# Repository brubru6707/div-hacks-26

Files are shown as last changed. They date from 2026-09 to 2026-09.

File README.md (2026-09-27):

# DivHacks 2026 — Pi 5 Demo Node

Camera + PIR motion node on a Raspberry Pi 5, verified 2026-09-23. All four hardware tests pass.

## Hardware
- Raspberry Pi 5 Model B Rev 1.1, Raspberry Pi OS Lite, Debian 13 (Trixie), 64-bit.
- Arducam IMX219 NoIR camera on **CAM0**.
- HC-SR501 PIR sensor: OUT → GPIO4 (pin 7), VCC → 5V, GND → pin 6.
- One 850nm IR LED board, powered by its own power bank (not wired to the Pi).
- Powered by a 5V/3A USB-C supply (held fine, `throttled=0x0`). A 5V/5A supply is recommended for headroom.

## Test results
| Test | Result | Notes |
|---|---|---|
| 1. System health | PASS | Pi 5, 64-bit, no undervoltage |
| 2. Camera | PASS | needed `dtoverlay=imx219,cam0` + reboot |
| 3. PIR sensor | PASS | clean MOTION/clear on GPIO4 |
| 4. PIR triggers camera | PASS | 25 captures on motion, IR-lit (see `captures/`) |

## Key fixes
- `camera_auto_detect=1` alone did **not** bind the IMX219. Added `dtoverlay=imx219,cam0` to `/boot/firmware/config.txt` and rebooted.
- `picamera2` is not installed and the Pi has no internet (802.1X Wi-Fi blocks macOS Internet Sharing). Use `rpicam-still` instead, or `sudo apt install python3-picamera2` on a non-802.1X network.

## Reaching the Pi
Login: `pi` / `YOURPASSWORD` (sudo uses the same password).

It's on a direct Mac→Pi Ethernet cable (interface `en8`) with no DHCP, so link-local only. IPv4 self-assign is unreachable from macOS; use IPv6 link-local:
```
for i in 1 2 3; do ping6 -c1 ff02::1%en8 >/dev/null; done   # warm the link
ndp -an | grep 2c:cf:67 | grep %en8                          # find fe80::…%en8
ssh pi@<that-address>
```
The neighbor entry goes stale fast; warm before each connect, or hold an `ssh -M` ControlMaster with `ServerAliveInterval=5`. For the event, put the Pi on a switch/router with DHCP or set static IPs on both ends to end the flakiness.

## Files
- `captures/` — 25 PIR-triggered frames (`trig_*.jpg`) plus `cam_test.jpg` (plain Test 2 still). `trig_081020.jpg` clearly shows a hand lit by IR.
- `pir_test.py` — Test 3: prints MOTION/clear on GPIO4.
- `trigger_capture.py` — Test 4: captures a photo (via `rpicam-still`) on each motion event.
- `enclosure/` — parametric 3D-printable case. `enclosure.scad` (OpenSCAD) and `build_stl.py` (trimesh) generate `stl/`: `base_with_pisugar.stl`, `base_no_pisugar.stl`, and `lid.stl`. The node includes a PiSugar battery pack under the Pi; it's removable, hence the two base variants.
- `enclosure/v2/` — the current case (sensors on the front wall, IR light + camera + PIR in a row). `stl/` is the print set: `v2_base_usb.stl` (no PiSugar) or `v2_base_pisugar.stl`, plus lid, stand, shroud, diffuser and a front-wall test plate. The IR light pocket is cut to the vendor drawing by `fit_ir_light.py`; see `V2_NOTES.md`.
- `HANDOFF-pi5-camera-pir-node.md` — full handoff for whoever receives the hardware.
- `HANDOFF-barn-owl-dashboard.md` — the dashboard (barn-owl.tech), recording pipeline, and training-data status. Code in `dashboard/` and `pi/`.
- `HANDOFF-solana.md` — Solana track plan: on-chain, tamper-proof recording hashes with a live chain log on the dashboard; why the Ledger is optional.

Scripts live in `~/node-test/` on the Pi.

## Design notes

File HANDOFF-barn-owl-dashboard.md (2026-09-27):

# Barn Owl: dashboard, recording pipeline, and training data

Handoff for everything built on top of the Pi 5 camera node on 2026-09-26
(DivHacks). The hardware bring-up is in `HANDOFF-pi5-camera-pir-node.md`; this
file covers what came after: the web dashboard, how footage is recorded and
stored, and where the training data stands.

This repo is public. Secrets are **not** in this file; it says where each one
lives instead.

---

## 1. What exists, in one minute

| Thing | Where |
|---|---|
| Dashboard (primary) | **https://barn-owl.tech** (DigitalOcean droplet, shared with jenzombie) |
| Dashboard (backup) | https://barn-owl.vercel.app (same code, same database, no 15 fps features) |
| Dashboard login | ask Bruno. Stored as `DASH_USER` / `DASH_PASS` in the Vercel project env and `/etc/barn-owl/env` on the droplet |
| Pi program | `pi/agent.py`, runs as systemd service `barn-owl` on the Pi, starts at boot |
| Web app code | `dashboard/` (Node, no framework) |
| Databases | MongoDB Atlas free tier (512 MB), database `barn_owl` (media + live state), and **Tiger Data** (Tiger Cloud, TimescaleDB) for the time series, see 5 |
| All 15 fps videos as one zip | https://barn-owl.tech/api/videos-zip (must be logged in) |

What the dashboard does:

- **Live** tab: camera view at **1 fps** (default) or **15 fps** (barn-owl.tech only), zoom presets **1× / 1.5× / 2× / 2.5×**, rotate, PIR motion status + "last motion", IR light toggle, **● Record / ■ Stop**.
- **Recordings** tab: every recording as a MongoDB entry, with a 1 fps preview player, the raw document (`{ } Entry`), delete, and storage used out of 512 MB.
- **Videos (15 fps)** tab: each recording's full-rate video next to the matching 1 fps preview (synced by time), plus downloads: MP4, original MJPEG, frame-times `.txt`, and **Download all (.zip)**.
- **Totals bar** (every tab): recordings count/time, Pi frames/time/size, MongoDB preview frames/size.
- The page **dims** and the top-right says **Pi offline** when the Pi stops checking in (15 s grace).
- A browser stays logged in for a year (signed cookie).

---

## 2. How it fits together

```
                    campus Wi-Fi ("Columbia University", open)
   Raspberry Pi 5  ─────────────────────────────────────────────►  barn-owl.tech (droplet, Caddy → Node :8771)
   pi/agent.py                                                     │  /api/pi          state + 1 fps preview (every 1–3 s)
     • camera: one rpicam-vid, 640×480 @ 15 fps MJPEG              │  /api/stream-in   15 fps live push (only while watched)
     • PIR GPIO23, IR GPIO4                                        │  /api/video-in    finished 15 fps recordings
     • writes 15 fps recordings to ~/barn-owl/recordings           │  /srv/barn-owl/videos  (.mjpeg .txt .mp4)
     • uploads them when done                                      ▼
                     └── falls back to barn-owl.vercel.app ──► MongoDB Atlas (barn_owl) ◄── both sites read/write
```

The Pi is behind campus NAT, so nothing can connect *to* it. The Pi always
calls out: it POSTs its state every 3 s when idle, every 1 s while someone is
watching or recording. The site answers with "is anyone watching", "is a
recording on", pending IR command, and zoom.

Both sites share one MongoDB, so whichever the Pi reaches, both dashboards
show the same thing. If barn-owl.tech is down the Pi switches to Vercel within
a second and retries the droplet every 60 s.

---

## 3. Training data (the important part)

### 3.1 How to record a clip

1. Open https://barn-owl.tech → **Live**.
2. Pick the **zoom** first (it is locked during a recording, and stored on the entry).
3. Turn the **IR light** on if shooting dark (it auto-offs after 2 min to avoid overheating; clips longer than that need it re-toggled).
4. **● Record**. Move the prop. **■ Stop**.
5. A few seconds later the clip appears on **Videos (15 fps)**. Recording keeps going even if you close the page or Wi-Fi drops (it uploads when the Pi is back online). Hard cap: 30 min per recording.

### 3.2 What a recording produces

| Copy | Resolution / rate | Where | Use |
|---|---|---|---|
| Original | 640×480, **15 fps**, MJPEG (quality 80), full sensor field of view | Pi: `~/barn-owl/recordings/<local-time>_<id>.mjpeg` and droplet: `/srv/barn-owl/videos/<id>.mjpeg` | **training** |
| Frame times | one line per frame: ms since start | `<same name>.txt` | exact timing; the camera can drop frames |
| MP4 | H.264, same frames, ~40× smaller | droplet only | watching |
| Preview | 480×360, ~1 fps, JPEG q60 (~14 KB) | MongoDB `frames` collection | browsing on the dashboard |

`<id>` is the MongoDB recording id. It matches across the Pi file, the droplet
file, the zip, and the dashboard entry.

### 3.3 Getting the data

- **Everything, from anywhere:** https://barn-owl.tech/api/videos-zip. Built fresh on each click. Files are named `<UTC start>Z_<id>.{mjpeg,txt,mp4}` and there is a `manifest.csv` (file, id, start, duration, frames, fps, zoom, sizes).
- **One clip:** Videos tab → download links on its card.
- **Straight off the Pi** (same network): `./pi/pull_recordings.sh` → `recordings/` in this repo (git-ignored).

Extracting frames:

```bash
# every frame of an original, as JPEGs
ffmpeg -f mjpeg -i clip.mjpeg -q:v 2 frames/clip_%05d.jpg
# every 5th frame (3 fps) to cut near-duplicates
ffmpeg -f mjpeg -i clip.mjpeg -vf "select=not(mod(n\,5))" -vsync vfr -q:v 2 frames/clip_%05d.jpg
```

The MJPEG is a plain concatenation of JPEGs, so `extract_frames.py`-style
readers that split on `FFD8…FFD9` also work.

### 3.4 Dataset status (as of 2026-09-26 ~20:15 UTC)

- **28 recordings at 15 fps → 17,288 frames, ~19 min**, 530 MB on the Pi. Zoom: 25 at 1×, 2 at 1.5×, 1 at 2×.
- **13 older recordings (18:00–18:40 UTC) are NOT usable alongside the rest**: they were captured before the fixes below, at 480×360, ~1 fps, and a **cropped (zoomed-in) field of view**. They exist only as 1 fps previews in MongoDB, not as videos.

### 3.5 Camera facts that matter for training

- **Field of view.** Asking rpicam for 640×480 used to select the sensor's 640×480 mode, which reads only the central 1280×960 of the 3280×2464 sensor (≈39 % of the view). The agent now forces `--mode 1640:1232:10:P` (full sensor, 2×2 binned) and scales to 640×480. Everything recorded from 18:52 UTC on uses the full view; earlier footage is the cropped one.
- **Zoom presets** are centred `--roi` crops of that full-view image. Up to 2.5× the crop is still ≥ 640×480 sensor pixels, so it is real detail, not an upscale. Keep the subject near the centre when zoomed.
- **Exposure is automatic** right now. To lock it (e.g. your teammate's IR-night settings) set `OWL_CAM_EXTRA="--gain 8 --shutter 30000 --awb greyworld"` in `/etc/barn-owl.env` on the Pi and `sudo systemctl restart barn-owl`. That applies to the live view, recordings and the demo alike. Those IR settings were tuned for a dark room and may blow out the steel table under room lights.
- NoIR camera: colours have a magenta cast; black synthetic fabric (and the prop) can glow under 850 nm IR. Training in grayscale sidesteps both.

### 3.6 Review of the footage so far, and what to shoot next

What's good: strong contrast between the black prop and the brushed steel,
many positions/headings, partial (edge) views, empty-table frames, a
string-only/cable negative, no clipped highlights (mean brightness ≈110/255).

What to change:

1. **Variety of background.** The same spot of the same table with the same bright lamp reflection and the same black box is in nearly every frame. The model can memorise those. Move the prop around the table, add the floor if the demo might be there, add distractors (hoodie, bag, hands, shoes, cables near the prop).
2. **Distances.** Record a set at each zoom preset (1×, 1.5×, 2×, 2.5×) or at three real camera heights. Match whatever the demo mount will be.
3. **Motion vs. near-duplicates.** Static-prop clips add frames but little information. Keep the prop moving; subsample static clips (every 5th frame).
4. **Negatives.** Empty table, string only, hands only, dark objects that aren't the rat.
5. **IR / dark footage.** None yet. Lights off, IR on (from the dashboard).
6. **Demo location.** If you find out where you present, record a couple of minutes there right before.
7. **Split by recording, not by frame.** Hold out whole recordings (whole sessions ideally) for validation; adjacent frames are near-identical and leak across a random split.

### 3.7 The string

The prop is pulled on a string for now. Options, best first:

1. **Label only the rat** (never the string) and include **string-only** clips as negatives. The model learns the string isn't the rat, no editing needed. If the demo also pulls the prop on a string, this is the right choice, because the model will see the string live.
2. **Clear fishing line** for future clips: close to invisible, especially under IR.
3. **Remove it afterwards** (thin dark line → mask → OpenCV `inpaint`). If you do, do it to *every* frame including negatives, or the inpainting smudge itself becomes a "rat is here" cue.

---

## 4. The Pi

| | |
|---|---|
| Model | Raspberry Pi 5, Raspberry Pi OS Lite (Debian 13), hostname `raspberrypi` |
| Login | user `pi` (password in `CREDENTIALS.txt` locally; it's also in `README.md`, so **change it**) |
| Wi-Fi | "Columbia University" (open network; the Pi's chip can't do the OWE variant, so the NetworkManager profile is plain open). Power saving **off** (it caused multi-second stalls). Address seen: `10.206.18.8` |
| Ethernet | `eth0` is link-local only (it used to wait for DHCP forever and reset the link) |
| SSH from a Mac on campus Wi-Fi | `ssh pi@10.206.18.8` (key auth set up from Bruno's Mac) |
| SSH over the cable | IPv6 link-local, see the older handoff. macOS keeps turning IPv6 off on the USB adapter: `networksetup -setv6LinkLocal "USB 10/100/1000 LAN"` |
| Service | `barn-owl` (`/etc/systemd/system/barn-owl.service`), code in `~/barn-owl/agent.py`, logs: `journalctl -u barn-owl -f` |
| Config | `/etc/barn-owl.env` (root-only): `OWL_URLS`, `OWL_TOKEN`, `OWL_PIR_PIN=23`, `OWL_IR_PIN=4`, `OWL_IR_MAX_ON=120`, optional `OWL_CAM_EXTRA`, `OWL_CAM_FPS`, `OWL_REC_DIR`, `OWL_STREAM_URL` |
| Extra package | `python3-pil` (shrinks previews) |

**Wiring (HC-SR501 PIR):** VCC → pin 2 or 4 (5 V), OUT (middle pin) → **pin 16 (GPIO23)**, GND → pin 6.
It was stuck on "Motion" for hours because **VCC and GND were swapped**; fixed.
Knobs: time-delay fully counter-clockwise (~3 s hold), jumper on **L**; the
sensitivity knob sets range. **IR light:** switched by **GPIO4**, auto-off after
2 min (`OWL_IR_MAX_ON`) because it overheats.

Deploying agent changes: copy `pi/agent.py` to `~/barn-owl/agent.py` and
`sudo systemctl restart barn-owl`.

---

## 5. Hosting

### Droplet (barn-owl.tech)

- The existing **jenzombie** droplet `104.248.231.139` (nyc1). barn-owl runs next to jenzombie; jenzombie is untouched except one line appended to `/etc/caddy/Caddyfile`: `import /etc/caddy/sites/*.caddy` (backup: `Caddyfile.pre-barn-owl`). **If jenzombie's own `provision.sh` is re-run it overwrites the Caddyfile and barn-owl disappears**; re-run barn-owl's provision (below) or add that import line to the jenzombie repo's `server/Caddyfile`.
- Node service `barn-owl-web` on `127.0.0.1:8771` (hardened unit; writes only `/srv/barn-owl/videos`). Secrets in `/etc/barn-owl/env`.
- Caddy site file `/etc/caddy/sites/barn-owl.caddy` (from `dashboard/deploy/barn-owl.caddy`): TLS, `flush_interval -1` for the live stream, and a log filter that deletes `Authorization`, `Cookie` and `Set-Cookie` (verified: 0 hits for the token in the log).
- DNS: DigitalOcean zone `barn-owl.tech`, A records for apex + `www` → droplet, TTL 300. Registrar (get.tech/Namify) nameservers → `ns1/ns2/ns3.digitalocean.com`. Let's Encrypt certs for both names.
- Deploy from a Mac:
  ```bash
  cd dashboard
  BO_HOST=root@104.248.231.139 BO_SITES="barn-owl.tech, www.barn-owl.tech, barn-owl.104-248-231-139.sslip.io" ./deploy/push.sh
  # add --secrets to (re)write /etc/barn-owl/env from dashboard/.env.local
  ```
  `push.sh` rsyncs the app and runs `deploy/provision.sh` on the droplet (idempotent: Node 22, ffmpeg, zip, user, service, Caddy, checks).

### Vercel (backup)

- Project `barn-owl` in the `brubru6707s-projects` team. `cd dashboard && vercel deploy --prod`.
- Env: `DASH_USER`, `DASH_PASS`, `SESSION_SECRET`, `PI_TOKEN`, `MONGODB_URI` (the last from the MongoDB Atlas integration). `vercel env pull` writes them to `dashboard/.env.local` (git-ignored).
- Vercel functions can't hold connections open, so **15 fps live, Videos and the zip only work on barn-owl.tech**. Vercel shows 1 fps and links to the droplet for videos.

### MongoDB (`barn_owl`)

| Collection | Contents |
|---|---|
| `node` | one document `{_id:'node'}`: Pi state, latest preview frame, viewer timestamps, pending IR command, zoom, recording in progress |
| `recordings` | one entry per Record→Stop: start/end/duration, zoom, preview count/bytes, `pi` (file/frames/fps/bytes), `video` (status/frames/fps/sizes) |
| `frames` | 1 fps preview JPEGs `{rec, ts, jpeg}` (kept out of `recordings` because a document is capped at 16 MB) |

Live viewing never adds storage (the `node` document is overwritten). Only
recording previews accumulate, ~14 KB/s of recording.

---

### Tiger Data (time series, for the "Best Use of Tiger Data" track)

MongoDB keeps media and live state; **Tiger Data (TimescaleDB on Postgres,
Tiger Cloud service `db-41897`, us-east-1)** keeps everything that happens over
time. Code: `dashboard/lib/tiger.js` (schema is created on first use, idempotent).

| Object | Kind | What |
|---|---|---|
| `readings` | hypertable (1 h chunks), **compressed** after 1 h (columnstore policy) | one row per Pi check-in: pir, ir, zoom, camera_on, recording, cpu_temp_c, wifi_dbm |
| `motion_events` | hypertable | one row per stretch of PIR motion (written on the rising edge, closed on the falling edge) |
| `detections` | hypertable | rat detections: ts, recording, frame, label, confidence, box x/y/w/h (0–1), model |
| `recordings` | table | same ids as MongoDB (41 backfilled with `deploy/backfill-tiger.js`); joins detections/motion to clips |
| `activity_1m`, `activity_1h` | continuous aggregates (hierarchical) | motion share, IR share, CPU temp per minute / hour |
| `detections_1m` | continuous aggregate | detections and best confidence per minute |

The dashboard's **Activity** tab reads only the continuous aggregates and
shows rows stored, compression saved, motion events, detections and query time.

**Posting detections (for the model):**
```bash
curl -X POST https://barn-owl.tech/api/detections \
  -H "Authorization: Bearer $PI_TOKEN" -H "Content-Type: application/json" \
  -d '[{"recording":"<recording id>","frame":123,"confidence":0.91,"box":[0.40,0.35,0.12,0.08],"model":"yolo-v1"}]'
```
Send one object or an array (a whole clip at once is one insert). `ts`
defaults to now; for offline runs over a downloaded clip, pass the frame's
real time (recording start + the `.txt` offset). `GET /api/detections` (logged
in) returns the latest 100.

Useful SQL (connect with the string in `~/.barn-owl/tiger_url` on Bruno's Mac):
```sql
-- rats per clip, best confidence
select r.id, r.started_at, count(d.*) as rats, max(d.confidence) as best
from recordings r left join detections d on d.recording = r.id
group by r.id order by r.started_at desc;
-- clips where the model saw a rat but the PIR never fired
select distinct d.recording from detections d
where not exists (select 1 from readings x where x.recording = d.recording and x.pir);
-- compression
select * from chunk_compression_stats('readings');
```

TLS: Tiger Cloud signs with its own root (`ca.timescale.com`), pinned in
`dashboard/lib/timescale-ca.pem` (expires 2027-10-20), so the connection is
verified rather than `rejectUnauthorized: false`. `TIGER_DATABASE_URL` is set
in Vercel and `/etc/barn-owl/env` on the droplet; without it the site runs as
before and the Activity tab says Tiger isn't configured.

## 6. Gotchas we hit (so you don't)

- The HC-SR501 read HIGH forever: VCC/GND swapped. Pulling OUT off pin 16 made the pin read LOW, which proved the Pi side was fine.
- The dashboard flickered offline: Wi-Fi power saving on the Pi's Broadcom chip. Disabled in the NetworkManager profile.
- "Zoomed in" camera: the 640×480 sensor mode is a centre crop (see 3.5).
- This Mac's resolver answers `127.0.0.1` for `barn-owl.tech` (something local intercepts DNS). Chrome works; `curl` on the Mac may not. Verify from the droplet instead.
- Chrome won't load `<video>` in a background tab, so automated checks of the Videos tab can look stuck when they aren't.
- Deleting a recording on the dashboard removes MongoDB + droplet copies but **not** the Pi original (on purpose).
- Zoom is locked during a recording; changing zoom restarts the camera (~2 s).

---

## 7. Costs and cleanup

- **Money:** only the droplet (~$6/mo), which was already running for jenzombie. The DO account had $3.65 signup credit on 2026-09-26 (≈17 days); after that the card on file is billed. Powering a droplet off does not stop billing; destroying it does. Vercel Hobby and MongoDB Atlas free tier: $0. `barn-owl.tech` is paid until 2027-09-26, **auto-renew off** ($29.99/yr).
- **To move off the droplet later for $0:** add `barn-owl.tech` to the Vercel project, point DNS at Vercel, destroy the droplet (only once jenzombie is done too). You'd lose 15 fps live/Videos/zip unless reworked.
- **Tiger Cloud:** 30-day trial ($1,000 credit, no card). Delete service `db-41897` when done or it will need a plan.
- **Secrets to rotate/revoke when done:** the Tiger Cloud `tsdbadmin` password (it was pasted into a chat); `PI_TOKEN` (Vercel env, droplet `/etc/barn-owl/env`, Pi `/etc/barn-owl.env`, Bruno's Mac `~/.barn-owl/pi_token`); `SESSION_SECRET`; the MongoDB Atlas user; the Pi password (public in `README.md`); the dashboard password (it's short, so change it before anything public).
- **Not committed yet (as of writing):** `dashboard/`, `pi/`, this file. `dashboard/.env.local` and `recordings/` are git-ignored.

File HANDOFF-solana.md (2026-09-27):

# Handoff — Solana track: tamper-proof recordings

Planning notes for adding Solana to Barn Owl for the DivHacks 2026 Solana track: what we decided and why. The first version is now built into the dashboard (next section). The Pi-side chunk hashing described further down is not built yet.

## What's built (2026-09-26): the dashboard's Solana tab
The **dashboard server** anchors evidence on Solana **devnet** with its own key. The Pi doesn't sign anything yet.

- **What gets anchored**
  - Every detection POSTed to `/api/detections`: the SHA-256 of a canonical JSON form of the row. Memo: `owl1 det <hash>`.
  - Every 15 fps recording the Pi uploads: the SHA-256 of the `.mjpeg` file. Memo: `owl1 rec <id> <hash>`. This runs on the droplet only (Vercel doesn't store the videos).
  - Up to 5 memos go in one transaction, signed by `SOLANA_ANCHOR_KEY`.
- **Code**
  - `dashboard/lib/solana.js`: hashing, a send queue (MongoDB collection `anchors`), confirmations, resends.
  - `dashboard/api/solana.js`: the tab's API.
  - Hooks: `api/detections.js` and `lib/videos.js`.
  - Anchoring never blocks or fails an upload. Anything unsent is retried whenever the tab polls, which also makes it work on Vercel.
- **The tab**
  - Anchor count, the key's address and balance (with an **Airdrop** button on devnet).
  - A **live chain log**: the browser subscribes to Solana over WebSocket (`logsSubscribe`), so rows flip to "✓ confirmed live" the moment the chain confirms them, without going through our server.
  - **Verify** on each row: the server recomputes the hash from the data as stored now (the Tiger Data row, or the file on disk), and the browser reads the memo from the chain itself and compares the two. For a detection, it lists which fields changed.
  - **Drop a file**: hash a downloaded original MJPEG in the browser and check it against the chain.
  - A "what this proves / doesn't" note.
- **Setup**
  - `SOLANA_ANCHOR_KEY` is a JSON byte array, like `solana-keygen` writes. It's in `dashboard/.env.local`; a backup is at `~/.config/solana/barn-owl-anchor-devnet.json`.
  - Optional: `SOLANA_CLUSTER` (default `devnet`), `SOLANA_RPC`, `SOLANA_PUBLIC_RPC`.
  - `deploy/push.sh --secrets` now ships `SOLANA_*` vars to the droplet. On Vercel, add the variable with `vercel env add SOLANA_ANCHOR_KEY`.
  - If the key isn't set, nothing is anchored and the tab says so.
- **Tamper demo:** change one field of a detection in Tiger Data (e.g. `update detections set confidence = 0.99 where …`), or flip a byte in a `.mjpeg` on the droplet, then press **Verify**.
- **Not built yet:** the Pi signing with its own key, and live 10-second chunk hashing while recording (both described below).

## TL;DR
- **Build:** the camera hashes its footage every ~10 seconds while recording and writes each hash to Solana (devnet). The dashboard shows those hashes landing on-chain **live**, next to the video.
- **Skip the Ledger** (the Nano S Plus won at a previous hackathon) unless there's time left at the end. It's a nice extra, not the core.
- **Don't use Solana to pay for the device.** That's just a checkout page and has nothing to do with what Barn Owl does.

## The pitch
Barn Owl is an unattended IR night camera. With this feature it becomes a camera that **proves its own footage hasn't been edited**:

> "Every 10 seconds of footage is fingerprinted and posted to Solana, signed by the camera itself. Watch the fingerprints confirm on-chain as the owl moves. Later, anyone can drop in a clip and check it wasn't cut or altered."

Why this fits Solana: it needs a chain that's fast (confirmations in about a second, so the ticker feels live) and cheap (hundreds of transactions per hour). This matters for wildlife research, citizen science and evidence of poaching or trespass.

## Ideas we considered
| Idea | Verdict |
|---|---|
| Pay for the device with Solana | ❌ Weak. It's generic e-commerce and doesn't use anything about the camera. |
| Hash each finished recording on-chain | ✅ Good, but you wait up to 30 min (the `REC_MAX`) for one hash. |
| **Hash ~10s chunks, linked together, shown live** | ✅✅ **Chosen.** Visual, real-time, and a stronger claim. |
| Solana Pay QR code: tip the node, or pay to turn on the IR light or start recording | 🟡 Stretch goal. Fits the existing dashboard → Pi commands. |
| Ledger as the owner/treasury key | 🟡 Optional, last. See below. |

## How it works

### Hash chaining
While a recording is on, the Pi groups frames into ~10s chunks. For each chunk:

```
chunk_hash_n = SHA256( prev_hash || SHA256(all JPEG bytes in chunk n) || frame times )
```

The first chunk uses the recording ID as `prev_hash`. Because each hash includes the one before it, the hashes form a chain: you can't delete, reorder or edit a chunk without breaking every hash after it.

Each chunk hash goes on-chain as a **Memo program** transaction (no custom smart contract needed), e.g.:

```
owl1|<recording id>|<chunk #>|<chunk hash hex>
```

### Who signs
- **The camera signs with its own key**: a Solana keypair generated on the Pi and stored on the SD card (e.g. `~/barn-owl/device-key.json`, mode 600). Keep only a little SOL in it for fees; on devnet, use the airdrop.
- The camera's public address is shown on the dashboard. Filtering the explorer by that address shows everything the camera has ever posted.

### Where the code goes
- `pi/agent.py`: `Recorder.write()` already sees every frame. Keep a running SHA-256 per chunk there, and every ~10s close the chunk, chain it, and queue the hash. `Recorder._close()` closes the final partial chunk.
- **Sending transactions:** we don't know yet whether the Pi will have normal internet at the venue (campus 802.1X Wi-Fi blocked it before; today it reaches the dashboard via `/api/pi`).
  - Plan: **the Pi always signs.** If it can reach a Solana RPC, it sends the transaction itself. If not, it hands the signed transaction to the dashboard in its normal `/api/pi` sync, and the server sends it. The camera's signature is what matters, so the proof holds either way.
  - Chunk hashes must be queued on disk so recordings made offline still get posted later (same idea as the existing `Uploader` and its `.uploaded` markers).
- **Dashboard:**
  - **Live chain-log panel** next to the video. The browser subscribes to Solana over WebSocket (`onLogs` on the camera's address), so rows appear the moment the chain confirms them. The page watches the chain itself rather than trusting our server.
    ```
    ● LIVE  Chain log — barn-owl-01
    21:04:12  rec 0419 #3  a3f9…c21e  ✓ confirmed  [explorer]
    21:03:58  rec 0419 #2  77b0…9e04  ✓ confirmed  [explorer]
    21:03:44  rec 0419 #1  e12c…0af3  ✓ confirmed  [explorer]
    ```
  - **"Verified on Solana ✓" badge** on each saved recording in the recordings list.
  - **Verify page:** drop in a downloaded `.mjpeg` + `.txt`, re-hash the chunks in the browser, and compare them with the on-chain memos. It shows ✓ for each chunk, or exactly which chunk was tampered with.
    - Chunk boundaries must be reproducible from the file alone. Split on the frame times in the `.txt` (e.g. every 10,000 ms), not on wall-clock time at record time.

### Build order
1. Generate the Pi device key and fund it on devnet. Post one test memo from the Pi, or through the dashboard relay.
2. Chunk hashing + chaining in `Recorder`, with an on-disk queue and posting.
3. Live chain-log panel on the dashboard.
4. Verified badge + verify page.
5. *(Stretch)* Solana Pay QR code for tips or "pay to turn on the IR light."
6. *(Stretch)* Ledger as owner (below).

## The Ledger — why we're skipping it
The question was: "would the Ledger make a hash for every recording, and would I see it on the Ledger?" **No.**

- A Ledger needs a **human to press a button for every signature**. The camera runs unattended at 3am, so it can't sign the recording hashes.
- Leaving the Ledger plugged into the Pi would be worse: whoever stole the Pi would get the main wallet.
- The Ledger's screen only shows a transaction while you're approving it. It can't display a live feed, so the "see hashes in real time" part belongs on the dashboard.

In a full design, the Ledger would be the **owner/treasury key**, kept away from the camera, used rarely: receiving tips (receiving doesn't even need it plugged in), moving funds out, approving a new camera, revoking a stolen one. The Pi's throwaway key signs the routine hashes. If the Pi is stolen, the thief gets a few cents of fees and the owner revokes that camera.

**Decision:** the hashing is the project, and the Ledger adds setup risk (Ledger Live, the Solana app, wallet connection, possibly blind signing) for little demo value. No judge will mark us down for skipping it. **If there's time at the end:** make the Ledger's address the recipient of Solana Pay tips and name it as the camera's "owner" in the pitch ("the owner key lives on hardware, away from the field device"). That's about 10 minutes of work.

If we do use it: install the Solana app on the Ledger through Ledger Live and connect via Phantom or Solflare on devnet. Plain transfers and memos don't need blind signing; a custom program probably would.

## Demo script
1. Show the dashboard: live video, an empty chain log, the camera's Solana address.
2. Press **Record**, then wave a hand in front of the camera under the IR light.
3. Within a couple of seconds, chunk hashes start scrolling into the chain log, each marked ✓ confirmed. Click one to open the Solana explorer and show the memo signed by the camera.
4. Stop the recording. It shows up with **Verified on Solana ✓**.
5. Download the clip, remove a few frames (or flip bytes), and drop it on the verify page. The chunks before the edit show ✓; the edited chunk and everything after it show ✗.
6. *(If built)* Someone scans the Solana Pay QR code and tips 0.01 SOL to the owner address.

## Open questions
- Will the Pi have normal internet at the venue? (Decides whether it sends transactions directly or through the dashboard; the plan supports both.)
- Chunk length: 10s is the working choice. Shorter makes the ticker livelier; longer means fewer transactions.
- Devnet only for the demo? (Assumed yes.)

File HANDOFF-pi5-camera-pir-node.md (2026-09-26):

# Handoff — Pi 5 Camera + PIR Motion Node (DivHacks 2026)

You're getting a Raspberry Pi 5 set up as a motion-triggered camera node. Everything below is what it is, how to get into it, and the few gotchas that will otherwise cost you an hour.

## What it does (already built and tested)
A PIR motion sensor triggers the camera to take a photo. The camera is a NoIR (no infrared filter), so with an IR light it sees in the dark. All four hardware checks passed on 2026-09-23:

| Check | Status |
|---|---|
| Pi 5 boots, 64-bit OS, no undervoltage | working |
| IMX219 camera detected and captures | working |
| PIR sensor reports motion on GPIO4 | working |
| Motion triggers a photo (25 IR-lit frames captured) | working |

Sample photos are in `captures/` in this folder. `trig_081020.jpg` shows a hand lit by infrared.

## What's in the box
- Raspberry Pi 5 with the microSD card already imaged (Raspberry Pi OS Lite, 64-bit).
- Arducam IMX219 NoIR camera, ribbon into the **CAM0** connector.
- HC-SR501 PIR sensor, wired to the Pi: OUT → GPIO4 (physical pin 7), VCC → 5V (pin 2 or 4), GND → pin 6.
- One 850nm IR LED board with its own power bank (this is a light, it does **not** connect to the Pi).
- **PiSugar battery pack** mounted under the Pi so the node can run untethered. It is removable — pop it off and power the Pi straight from USB-C. The case has two variants for exactly this (see the enclosure section).
- Camera ribbon is ~12 cm, so the camera can sit up to that far from the Pi.

## Login
```
username: pi
password: YOURPASSWORD
```
`sudo` uses the same password. Please change it once you're in (`passwd`).

## Powering it
Use a **5V/3A USB-C supply minimum**; a 5V/5A (27 W) official Pi 5 supply is better and gives headroom for the camera. A phone charger rated only 2A will not boot a Pi 5 reliably. It ran clean on 3A during testing.

## Getting into the Pi — pick the easiest for your setup

**Option A — monitor + keyboard (simplest).** Plug a monitor into the **micro-HDMI port nearest the USB-C jack**, add a USB keyboard, power on, and log in with the credentials above. No network needed.

**Option B — network with a router/switch (best for headless).** Plug the Pi's Ethernet into any router or switch that hands out addresses (DHCP). SSH is already enabled. From another computer on that network:
```
ssh pi@raspberrypi.local
```
If the name doesn't resolve, find the Pi's IP in your router's device list and use `ssh pi@<ip>`.

**Option C — direct cable straight to a laptop (what we did, and it's fiddly).** With no router there's no DHCP, so both ends fall back to link-local addressing, which is flaky and OS-specific. On macOS it took IPv6 link-local gymnastics (see `README.md` in this folder for the exact commands). **Avoid this if you can.** Use Option A or B instead.

**Wi-Fi is not configured.** If you want wireless, connect by Option A or B first, then run `sudo raspi-config` (or `nmcli`) to add your network.

## Running the demo
The test scripts are on the Pi in `~/node-test/` (copies are also in this folder):
```
python3 ~/node-test/pir_test.py          # prints MOTION / clear as you wave at the PIR
python3 ~/node-test/trigger_capture.py   # takes a photo on each motion event
```
Stop either with Ctrl+C. For the camera-in-the-dark demo, power the IR board, aim it where the camera looks, dim the room, and wave your hand in view.

## 3D-printed enclosure
Case files are in `enclosure/`. Two base variants share one lid:

| File | Fits | Outer size (mm) |
|---|---|---|
| `stl/base_with_pisugar.stl` | Pi **with** the PiSugar under it | 93 × 64 × 43 |
| `stl/base_no_pisugar.stl` | Pi only (PiSugar removed) | 93 × 64 × 30 |
| `stl/lid.stl` | camera + PIR mount on top | 93 × 64 × 7 |

The only difference between the two bases is height: the PiSugar variant is ~13 mm taller to make room for the pack. The lid has a lens hole plus four Arducam (M2) mount holes near one end, and a 23.5 mm hole for the PIR dome near the other. Port openings are cut for the USB/Ethernet edge and the USB-C/HDMI edge.

Re-render after any change with either tool:
- `enclosure/enclosure.scad` in OpenSCAD (parametric; `include_pisugar` toggle), or
- `python3 enclosure/build_stl.py` (needs `pip install trimesh manifold3d numpy`).

Key parameters: `pisugar_h` (default 15 mm), wall thickness, clearances, and the port-window positions.

**Print + verify first.** The STLs are watertight and printable, but the dimensions were typed from measurements, not imported from a CAD model of the boards. Before a full print, dry-fit or print a test and check: the PiSugar height, the port windows against your board's actual orientation, and the camera/PIR hole placement. Nudge the parameters and re-render as needed.

## Gotchas that will bite you
- **microSD write-protect lock.** If you ever re-flash the card and writes are "permission denied," check the tiny slider switch on the card/adapter. It must be unlocked.
- **Camera needs an overlay.** `dtoverlay=imx219,cam0` is already in `/boot/firmware/config.txt` (backup at `config.txt.bak`). Auto-detect alone did not find the camera. If you swap SD images, you'll need to add that line again and reboot.
- **`picamera2` is not installed** and the Pi had no internet during setup, so the trigger script uses `rpicam-still`. If you want `picamera2`, put the Pi on internet once and run `sudo apt install python3-picamera2`.
- **The OS is Debian 13 (Trixie), 64-bit** — newer than the Bookworm most guides assume. Package names occasionally differ.
- **Verify the IR board is on** by pointing a phone camera at it; you'll see a purple-white glow. Your eyes can't see 850nm.

## Quick sanity check once you're in
```
cat /proc/device-tree/model        # Raspberry Pi 5 ...
vcgencmd get_throttled             # want throttled=0x0
rpicam-hello --list-cameras        # should list imx219
```

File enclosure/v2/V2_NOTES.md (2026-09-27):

# Enclosure v2

`node_v2.scad` is a new case built from the measured parts (Pi 5 + Active Cooler + PiSugar 3 Plus, Arducam IMX219, HC-SR501, IR light board). The v1 files are untouched.

Two power variants share the same lid, sensor wall and extras. Only the base differs:

| Variant | Base file | Power | Outer size (with lid) |
|---|---|---|---|
| **USB** | `stl/v2_base_usb.stl` | USB-C cable from a power bank, in through the side window | 107 × 96 × 45 mm |
| **PiSugar battery** | `stl/v2_base_pisugar.stl` | PiSugar 5000 mAh pack clipped magnetically under the PiSugar, inside the case. Charge through the same side window. | 107 × 96 × 57 mm |

In the battery variant the stack rests on the battery. A shallow tray locates the pack, and two walls stop the stack sliding toward the sensors or the cable bay. The pack is 67 × 55 × 12 mm as measured, with 3 mm of play on each side.

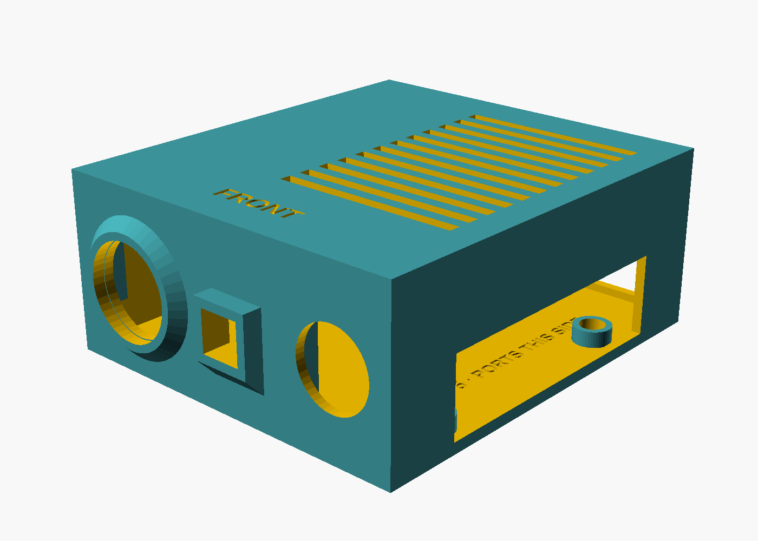
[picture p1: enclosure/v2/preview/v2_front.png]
front

inside

## What changed from v1

| | v1 | v2 |
|---|---|---|
| Sensors | camera + PIR on the lid, facing up | IR light, camera, PIR in one row on a flat **front** wall that presses against the diorama |
| USB-A / Ethernet | no opening (the port end faced a solid wall) | open **rear** wall |
| USB-C / HDMI / PiSugar ports | window on the wrong edge | window on the **port side**, tall enough for the PiSugar below the Pi |
| PIR vs USB stack | PIR above the USB ports (collision) | PIR beside the Pi, clear of it |
| Camera hole | 9 mm round (the square lens holder's diagonal doesn't fit) | 10.5 mm square, plus an outside hood so IR light doesn't flare into the lens |
| Cooling | one vent row | grille in the lid over the Active Cooler fan, plus side vents |
| Mounting | self-tap standoffs | sockets the PiSugar's studs drop into |
| Extras | none | cable bay beside the Pi, PIR shroud, clear PETG diffuser for the IR light |

## Print

| File | Material | Notes |
|---|---|---|
| `stl/v2_test_plate.stl` | black PLA | **Print this first** (front wall only). Check that the three sensors fit. |
| `stl/v2_base_usb.stl` or `stl/v2_base_pisugar.stl` | black PLA | Pick one. Prints as oriented (open top up). |
| `stl/v2_lid.stl` | black PLA | Already flipped: flat face down. |
| `stl/v2_stand.stl` | black PLA | Tilts the box 20° nose-down so the camera sees the floor. `tilt` in the file. |
| `stl/v2_pir_shroud.stl` | black PLA | Slides over the collar around the PIR dome to narrow its view. |
| `stl/v2_led_diffuser.stl` | clear PETG | Optional cap over the IR lens; softens the hot spot. |

Settings: 0.2 mm layers, 3 walls, 15% infill, no supports needed (the camera hood and PIR collar taper at 45° underneath). Glue stick for PETG. Don't print PLA and PETG fused together; they don't bond.

## Assembly
1. USB variant: drop the Pi + PiSugar stack onto the four sockets. Battery variant: clip the pack onto the PiSugar's magnet, plug its lead into the PiSugar's white socket, and set the whole stack in the tray. Either way, microSD end toward the front and USB-C/HDMI edge toward the port-side window ("PI 5 · PORTS THIS SIDE" is engraved on the floor).
2. Camera: lens holder through the square hole, board slides down between its rails, ribbon connector at the bottom. Hot-glue it.
3. IR light: lens through the round hole on the port side, board slides between the two rails. Hot-glue it. Its power lead runs along the sensor zone into the cable bay and out through the small rear notch.
4. PIR: dome through the big hole, board between its rails, hot-glue. Wires run to the GPIO header.
5. Lid on, with "FRONT" toward the sensor wall.
6. Set the box on the stand, front bottom edge against the lip. The holes in the diorama's back wall need to be a little taller than the sensors because the box is tilted.

## Assumptions to check on the test plate
- ~~IR light board is 21 mm wide (rails 21.8 mm apart).~~ Superseded by the measured fit below. PIR board is 32 mm wide.
- PiSugar ports are on the same long edge as the Pi's USB-C/HDMI (checked against the underside photo: the camera ribbon, which plugs into that edge, exits beside the PiSugar's ports).
- Battery variant: the stack sits loosely on the pouch. Add a strip of double-sided foam tape if it rattles. Don't let anything sharp press on the pouch, and don't use a pack that has puffed up.

Set `power = "usb"` or `"pisugar"` at the top of `node_v2.scad`. All sizes are variables there too. Change a number and run `./build_v2.sh` (needs OpenSCAD 2025+). **`node_v2.scad` is not in this repo**, only the STLs it produced (`original/`); see the next section for how the IR light fit is applied on top of them.

## IR light board fit (2026-09-25)

The vendor drawing for the 850 nm IR light replaces the guessed size. `fit_ir_light.py` patches the v2 STLs (the `.scad` isn't here, only its output) and writes the complete print set to `stl/`. The untouched v2 files stay in `original/`. Previews: `preview/v2_ir_fit_3d.png`, `preview/v2_ir_fit_sections.png`.

| | v2 guess | drawing |
|---|---|---|
| PCB | 21 wide | 19.82 × 27.94 × 1.0 mm, D-shaped (R10 top), solder pads 13.66 apart at the bottom ears |
| Lens | 19 dia (hole 19.8) | 19.0 dia, front face 14.05 in front of the PCB |
| Photoresistor | not modelled | 5.0 dia, tip 8.35 in front of the PCB, lower right of the lens seen from the front |
| Beam | | 100° |

What changed in the sensor wall (both bases, and the test plate):

- **Photoresistor hole**, 6.4 mm, merged with the lens hole into a keyhole. Without it the board could not get closer than 8.35 mm to the wall.
- **The PCB now seats 8.35 mm behind the outside face**, so the photoresistor tip is flush with the outside and the lens stands 5.7 mm proud, the same as the PIR collar and the camera hood. (v2 had the PCB against the wall and the lens 11.6 mm proud.) `PCB_FACE_X` in the script; set it to `2.4` for the old behaviour.
- **Rails** 20.4 mm apart (was 21.8) and 10.6 mm deep (was 5), from the floor to just above the lens axis. Three stops set the PCB depth: a post under the lens barrel (over the notch between the pads), a lip on the right, and a short lip on the left above the photoresistor. Hot-glue the board from behind, as before.
- `v2_led_diffuser.stl` is regenerated 7.2 mm tall for the shorter protrusion.
- `v2_lid.stl`, `v2_stand.stl`, `v2_pir_shroud.stl` are unchanged copies.

Assembly change for step 3: the IR board goes in from **behind**, straight along the lens axis. Lens into the round hole, photoresistor into the small hole, push until the PCB meets the stops. Solder the power wires on the back of the PCB first; they exit toward the cable bay.

Check on the test plate:

- Photoresistor position: 7.0 mm right / 9.3 mm below the lens axis was scaled off the drawing, so its hole is 1.4 mm oversize. If it doesn't line up, change `LDR_DX` / `LDR_DY` and rerun.
- The 8.35 was read as photoresistor tip to the PCB *front* face. If it is to the back face, the tip sits 1 mm inside the wall. Harmless.
- The centre post assumes the notch between the pads is at most ~4 mm deep (post top is 7 mm above the PCB's bottom edge). If the notch is deeper, the post misses and the two side lips set the depth alone.
- The PCB's bottom edge sits 1.06 mm above the floor.

```sh
pip install trimesh manifold3d numpy matplotlib
python3 enclosure/v2/fit_ir_light.py
```

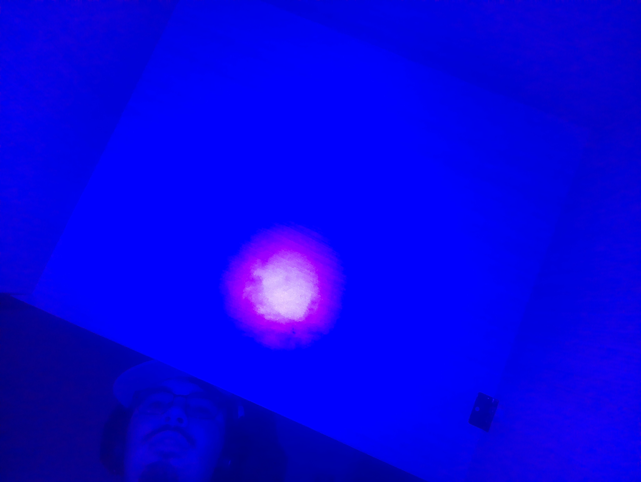
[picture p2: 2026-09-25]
captures/trig_081120.jpg

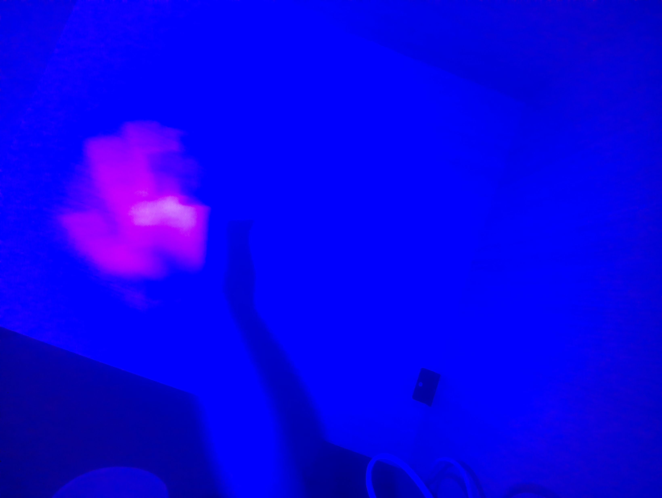
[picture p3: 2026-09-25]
captures/trig_081028.jpg

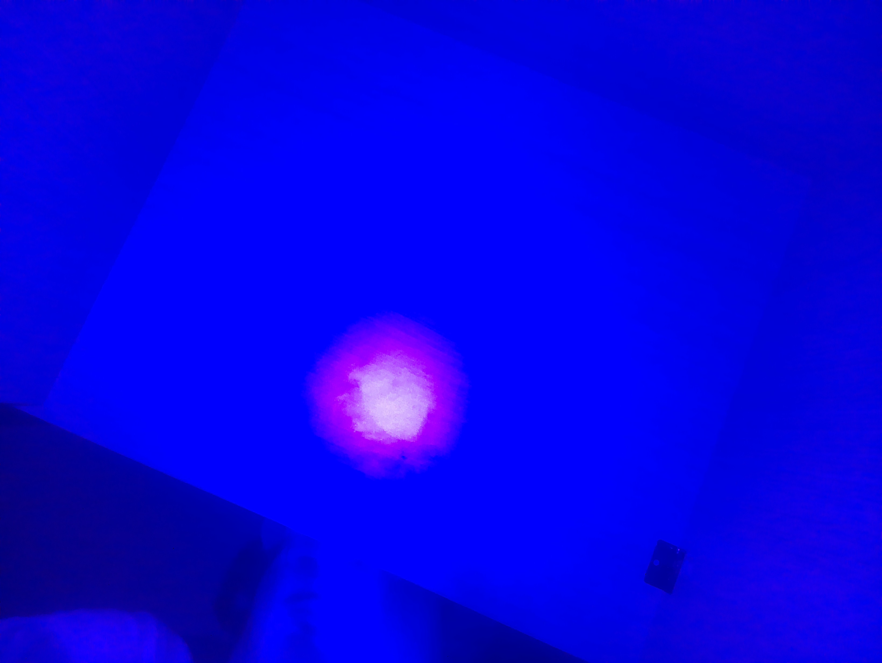
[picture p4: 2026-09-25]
captures/trig_081124.jpg

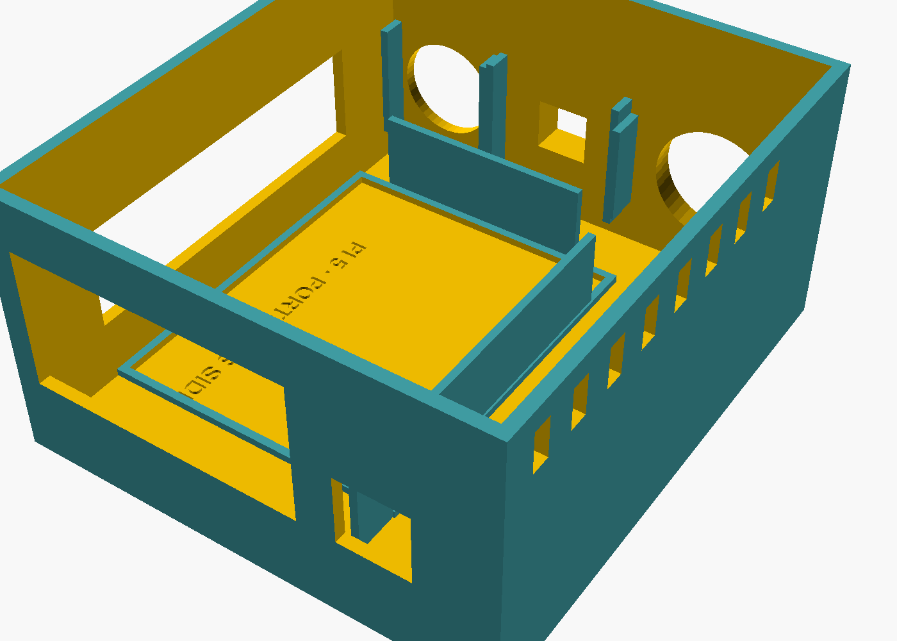
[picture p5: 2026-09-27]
enclosure/v2/preview/v2_inside_pisugar.png

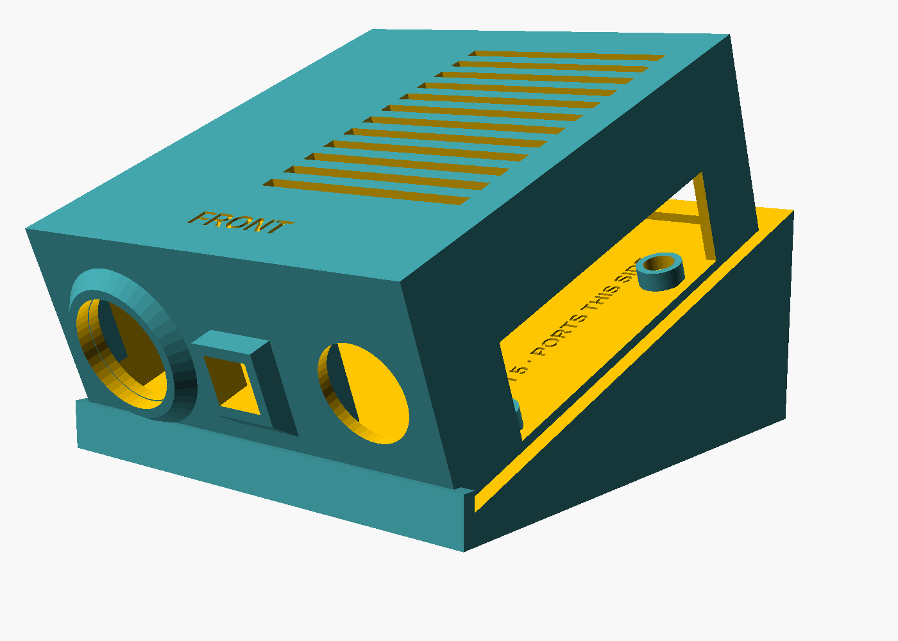
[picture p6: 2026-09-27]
enclosure/v2/preview/v2_on_stand.png

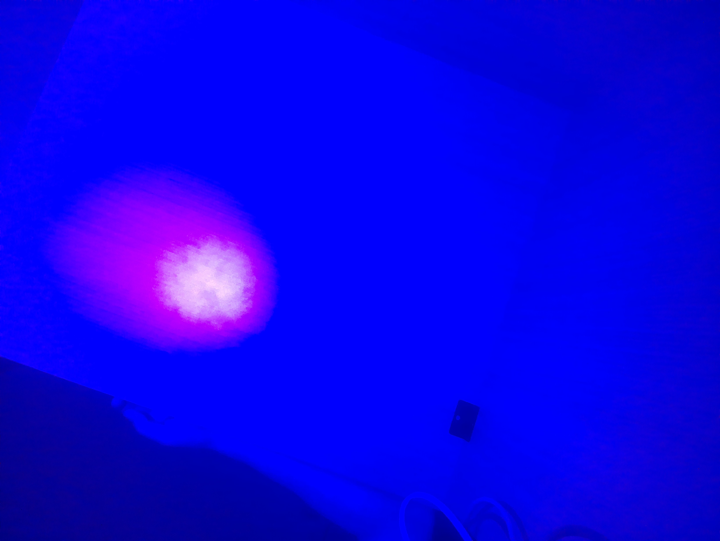
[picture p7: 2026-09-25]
captures/trig_080957.jpg

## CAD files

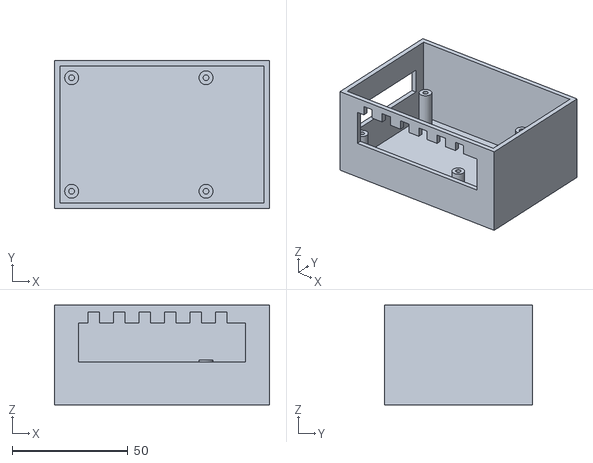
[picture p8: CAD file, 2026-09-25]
enclosure/stl/base_with_pisugar.stl
92.8 x 63.8 x 43.0

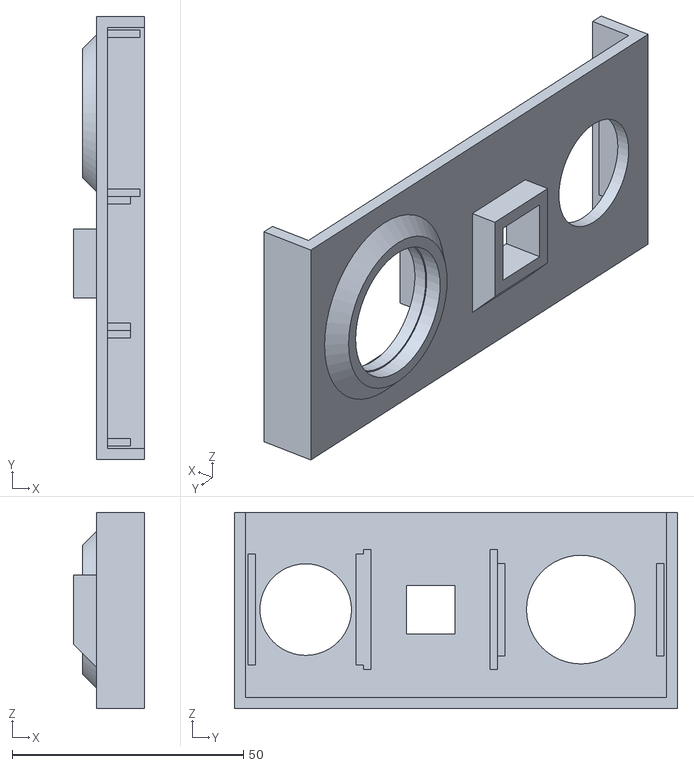
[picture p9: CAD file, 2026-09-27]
enclosure/v2/original/v2_test_plate.stl
15.4 x 95.8 x 42.4

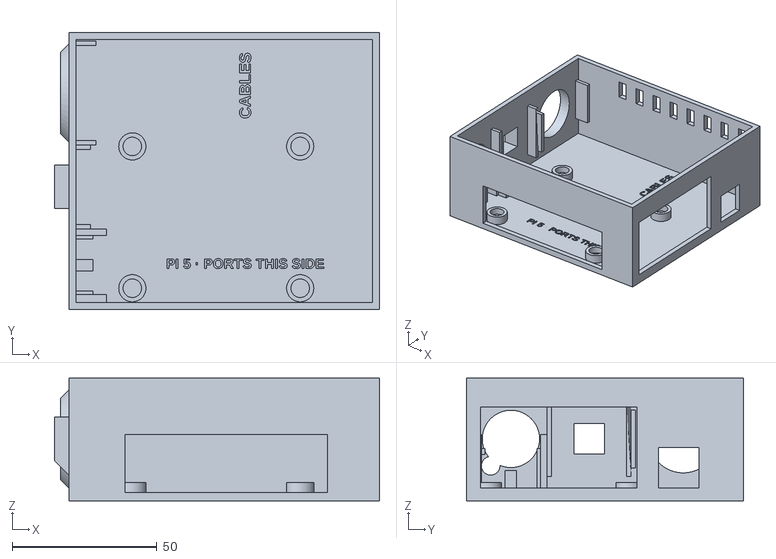
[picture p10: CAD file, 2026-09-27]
enclosure/v2/stl/v2_base_usb.stl
112.3 x 95.8 x 42.4

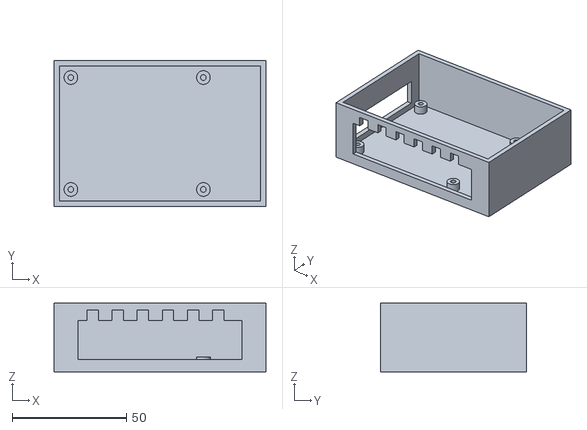
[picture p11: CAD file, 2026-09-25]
enclosure/stl/base_no_pisugar.stl
92.8 x 63.8 x 30.0

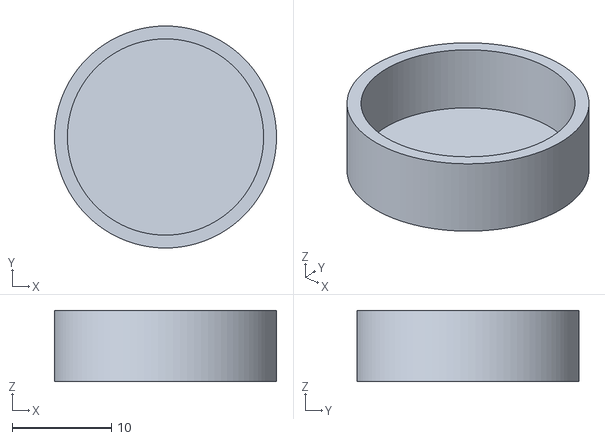
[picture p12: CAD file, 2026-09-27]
enclosure/v2/stl/v2_led_diffuser.stl
22.4 x 22.4 x 7.20

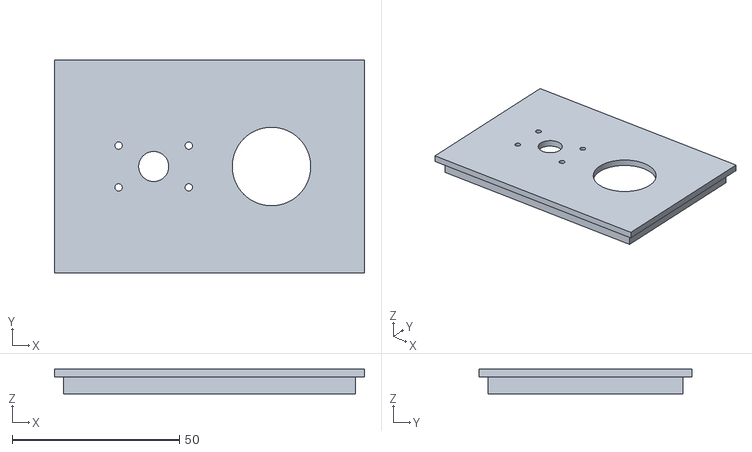
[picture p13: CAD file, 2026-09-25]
enclosure/stl/lid.stl
92.8 x 63.8 x 7.40

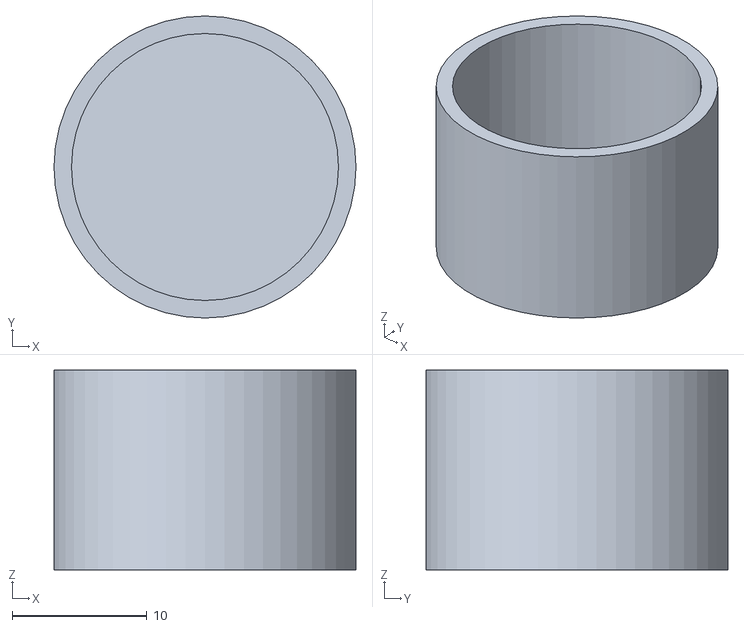
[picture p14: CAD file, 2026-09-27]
enclosure/v2/original/v2_led_diffuser.stl
22.4 x 22.4 x 14.8

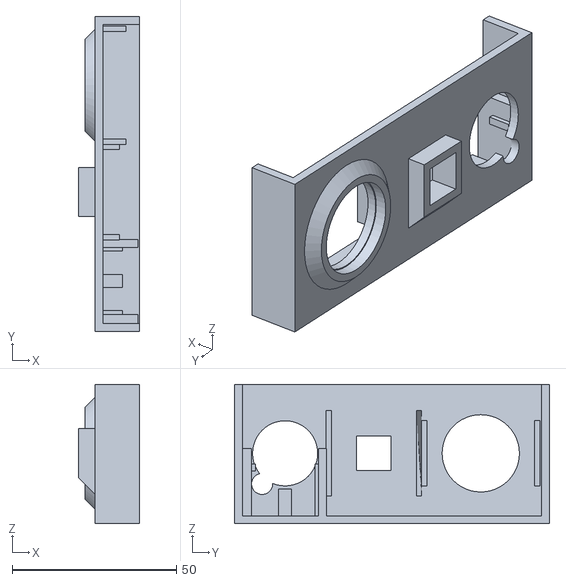
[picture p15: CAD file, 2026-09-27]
enclosure/v2/stl/v2_test_plate.stl
18.5 x 95.8 x 42.4

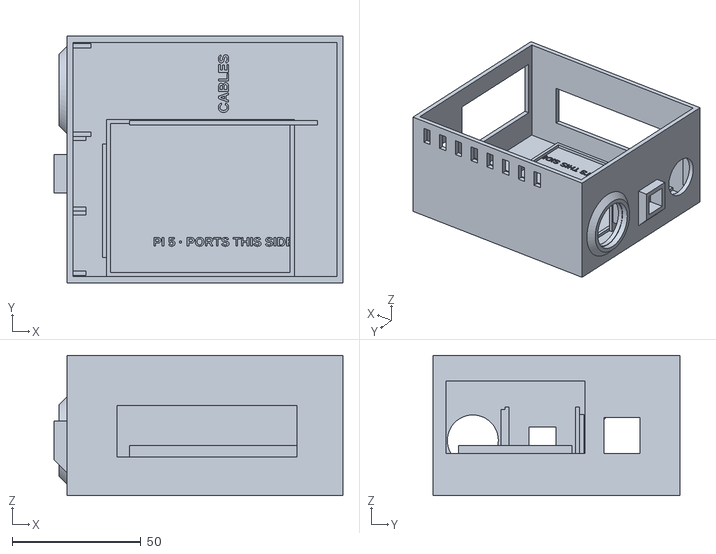
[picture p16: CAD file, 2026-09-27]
enclosure/v2/original/v2_base_pisugar.stl
112.3 x 95.8 x 54.4

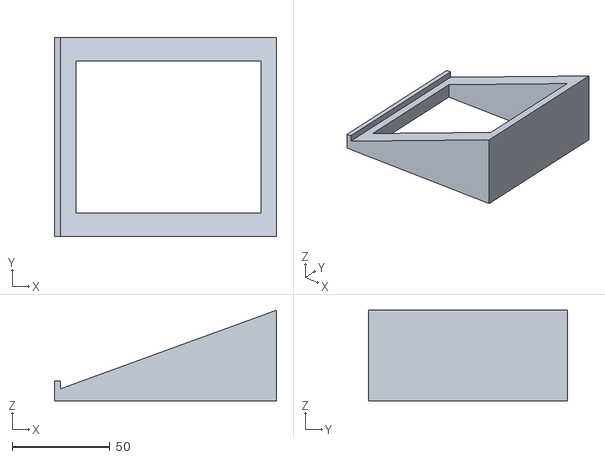
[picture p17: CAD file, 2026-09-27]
enclosure/v2/original/v2_stand.stl
113.3 x 101.8 x 46.2

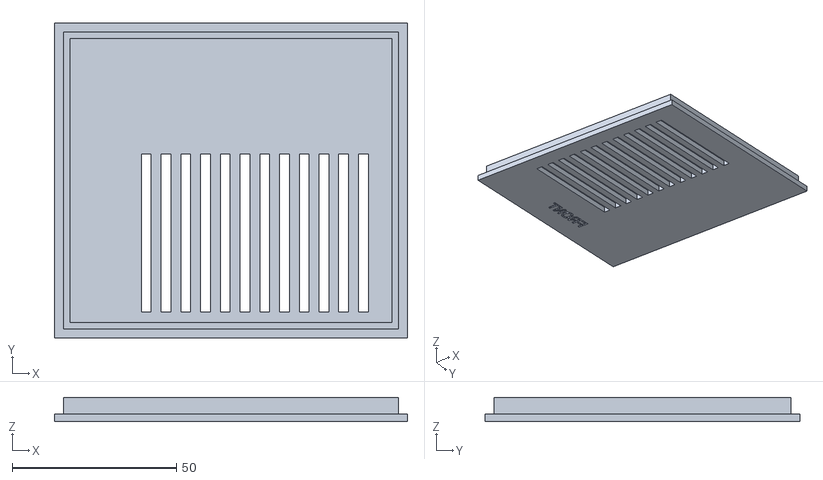
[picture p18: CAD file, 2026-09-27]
enclosure/v2/original/v2_lid.stl
107.3 x 95.8 x 7.40

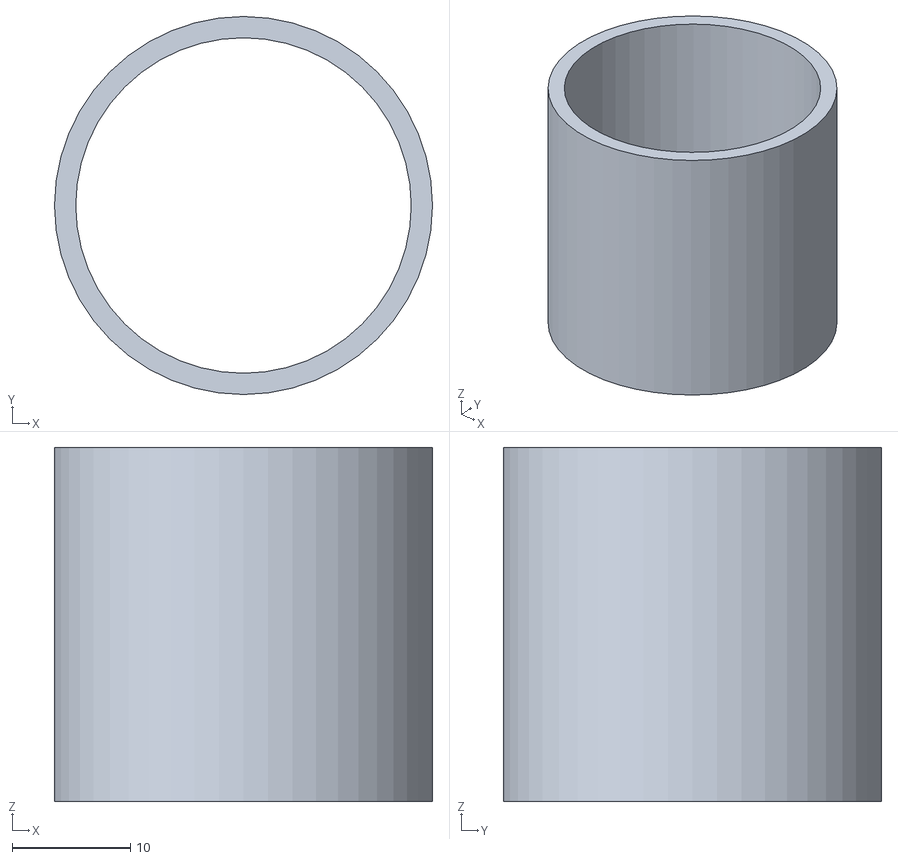
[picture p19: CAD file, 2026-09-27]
enclosure/v2/stl/v2_pir_shroud.stl
32.0 x 32.0 x 30.0

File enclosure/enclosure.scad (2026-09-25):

// DivHacks 2026 — Pi 5 Camera + PIR node enclosure (parametric)
// Renders a base tray + lid. Camera and PIR mount on the lid.
// Two build variants via include_pisugar:
//   true  -> taller base to fit a PiSugar battery pack under the Pi
//   false -> shorter base, Pi mounts low
//
// Render from CLI, e.g.:
//   openscad -D 'part="base"' -D 'include_pisugar=true'  -o base_pisugar.stl   enclosure.scad
//   openscad -D 'part="base"' -D 'include_pisugar=false' -o base_nopisugar.stl enclosure.scad
//   openscad -D 'part="lid"'                              -o lid.stl           enclosure.scad
//
// !! Verify PiSugar height and port positions against the real hardware before printing. !!

/* ---------- what to render ---------- */
part = "all";           // "base", "lid", or "all" (all = preview both, side by side)
include_pisugar = true; // battery-pack variant

/* ---------- measured component sizes ---------- */
pi_len   = 85;   // Pi 5 PCB length (mm)
pi_wid   = 56;   // Pi 5 PCB width
pi_pcb_t = 1.6;  // PCB thickness
pi_comp_h = 20;  // clearance needed above the PCB for USB/Ethernet/GPIO stack

pisugar_h = 15;  // battery pack height under the Pi  (MEASURE YOURS)

// Pi 5 mounting holes: 58 x 49 mm spacing, 3.5 mm in from the board edges, M2.5
hole_dx = 58;
hole_dy = 49;
hole_inset = 3.5;
screw_d = 2.5;   // self-tapping into plastic standoff; use 2.8 for M2.5 heat-inserts

// Arducam IMX219 module ~ 25 x 24 mm; lens in the middle
cam_body = 26;       // you measured 2.6 cm
cam_lens_hole = 9;   // hole for the lens barrel
cam_mount_dx = 21;   // Arducam mount hole spacing X
cam_mount_dy = 12.5; // Arducam mount hole spacing Y
cam_mount_d = 2.2;   // M2

// HC-SR501 PIR: PCB ~32 x 24, white dome ~23 mm diameter sticks through
pir_dome_d = 23.5;

/* ---------- case parameters ---------- */
wall = 2.4;
floor_t = 2.4;
clear = 1.5;             // gap around the board
under_gap = include_pisugar ? (pisugar_h + 2) : 4;  // floor-to-PCB gap
inner_l = pi_len + 2*clear;
inner_w = pi_wid + 2*clear;
inner_h = under_gap + pi_pcb_t + pi_comp_h;          // internal clear height
lid_lip = 6;             // depth of lid lip that inserts into the base
eps = 0.01;

/* ---------- helpers ---------- */
module standoff(h) {
    difference() {
        cylinder(h=h, d=6, $fn=40);
        translate([0,0,h-5]) cylinder(h=6, d=screw_d, $fn=30);
    }
}

// four corner-ish standoffs at the Pi hole positions
module standoffs(h) {
    x0 = wall + clear + hole_inset;
    y0 = wall + clear + hole_inset;
    for (dx=[0,hole_dx], dy=[0,hole_dy])
        translate([x0+dx, y0+dy, floor_t-eps]) standoff(h);
}

// a rectangular port window cut through a wall
module port_window(w, h, zoff) {
    translate([-eps, -eps, floor_t+zoff]) cube([w, wall+2*eps, h]);
}

module base() {
    ext_l = inner_l + 2*wall;
    ext_w = inner_w + 2*wall;
    difference() {
        // solid outer shell
        cube([ext_l, ext_w, floor_t + inner_h]);
        // hollow it
        translate([wall, wall, floor_t])
            cube([inner_l, inner_w, inner_h + eps]);

        // PORT WINDOWS  (adjust to your board orientation before printing)
        // long edge (y=0): USB x4 + Ethernet band
        translate([wall+8, 0, 0]) port_window(inner_l-16, 17, under_gap-1);
        // short edge (x=0): USB-C power + 2x micro-HDMI band
        translate([0, wall+6, 0])
            rotate([0,0,90]) port_window(inner_w-12, 12, under_gap-1);

        // side vent slots
        for (i=[0:5])
            translate([wall+12+i*11, -eps, floor_t+inner_h-9])
                cube([5, wall+2*eps, 6]);
    }
    standoffs(under_gap);
}

module lid() {
    ext_l = inner_l + 2*wall;
    ext_w = inner_w + 2*wall;
    cx = ext_l*0.32;   // camera cluster near one end
    px = ext_l*0.70;   // PIR near the other end
    cy = ext_w/2;
    difference() {
        union() {
            // top plate
            cube([ext_l, ext_w, wall]);
            // inner lip that drops into the base
            translate([wall+0.3, wall+0.3, -lid_lip])
                cube([inner_l-0.6, inner_w-0.6, lid_lip]);
        }
        // camera lens hole + mount holes
        translate([cx, cy, -lid_lip-eps]) cylinder(h=wall+lid_lip+1, d=cam_lens_hole, $fn=50);
        for (mx=[-cam_mount_dx/2, cam_mount_dx/2], my=[-cam_mount_dy/2, cam_mount_dy/2])
            translate([cx+mx, cy+my, -lid_lip-eps]) cylinder(h=wall+lid_lip+1, d=cam_mount_d, $fn=30);
        // PIR dome hole
        translate([px, cy, -lid_lip-eps]) cylinder(h=wall+lid_lip+1, d=pir_dome_d, $fn=60);
        // hollow the lip so it is a rim, not a block
        translate([wall+2.7, wall+2.7, -lid_lip-eps]) cube([inner_l-6, inner_w-6, lid_lip]);
    }
}

/* ---------- output ---------- */
if (part == "base") base();
else if (part == "lid") lid();
else { // "all": preview
    base();
    translate([0, inner_w + 3*wall + 8, 0]) lid();
}

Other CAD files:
enclosure/v2/original/v2_base_usb.stl
enclosure/v2/stl/v2_base_pisugar.stl
enclosure/v2/stl/v2_stand.stl
enclosure/v2/original/v2_pir_shroud.stl
enclosure/v2/stl/v2_lid.stl

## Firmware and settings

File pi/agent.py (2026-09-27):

#!/usr/bin/env python3
"""Barn Owl agent: keeps the dashboard up to date and takes IR commands from it.

The Pi sits behind campus NAT, so the dashboard can't reach it; instead this
POSTs to /api/pi on a loop. Idle it syncs every IDLE_INTERVAL seconds (a
heartbeat, so the site knows it's online). When someone has the dashboard
open, the site says so and this switches to streaming camera frames.

One camera stream runs at full rate (15 fps). While a recording is on, every
frame goes to a file under OWL_REC_DIR, which is then uploaded to the droplet
for the dashboard's Videos tab (see Uploader). The dashboard normally gets a small
1 fps preview; when someone picks "15 fps" on barn-owl.tech, every frame is
also pushed over one long-lived connection to the droplet (see Streamer).

"Rat detection" on the dashboard runs the team's rat model on the live frames
(see RatDetector): boxes are drawn on the preview and the 15 fps view (never on
the recordings, which stay clean training data), and each confirmed sighting is
POSTed to /api/detections.
"""
import base64
import glob
import http.client
import io
import json
import os
import shlex
import socket
import subprocess
import threading
import time
import urllib.parse
import urllib.request

from gpiozero import DigitalOutputDevice, MotionSensor

try:
    from PIL import Image, ImageDraw
except ImportError:  # previews are then sent full size, and without boxes
    Image = ImageDraw = None

# Comma-separated, primary first (the droplet), then backups (Vercel). Both
# sites share one database, so whichever the Pi reaches, both dashboards update.
URLS = [u.strip().rstrip("/") + "/api/pi" for u in
        os.environ.get("OWL_URLS", os.environ.get("OWL_URL", "")).split(",") if u.strip()]
RETRY_PRIMARY_AFTER = 60  # seconds on a backup before trying the primary again
TOKEN = os.environ["OWL_TOKEN"]
PIR_PIN = int(os.environ.get("OWL_PIR_PIN", 23))
IR_PIN = int(os.environ.get("OWL_IR_PIN", 4))
IR_MAX_ON = float(os.environ.get("OWL_IR_MAX_ON", 120))  # overheat guard, seconds
IDLE_INTERVAL = 3  # also how fast it notices a viewer or a recording starting
LIVE_INTERVAL = 1  # dashboard preview rate: 1 fps
PREVIEW_SIZE = (480, 360)
PREVIEW_QUALITY = 60  # ~12 KB a frame, vs ~37 KB for the full-rate recording
# The 15 fps live view needs a server that can hold a connection open: the
# droplet, not Vercel. Defaults to the first URL.
STREAM_URL = os.environ.get("OWL_STREAM_URL", URLS[0][:-len("/api/pi")] if URLS else "").rstrip("/")
ZOOMS = (1.0, 1.5, 2.0, 2.5)
FPS = int(os.environ.get("OWL_CAM_FPS", 15))
REC_DIR = os.path.expanduser(os.environ.get("OWL_REC_DIR", "~/barn-owl/recordings"))
REC_MAX = 30 * 60  # seconds; the dashboard enforces the same limit
# The rat model runs in its own venv (numpy, OpenCV, ONNX Runtime) via pi/rat_worker.py; see RatDetector.
DETECT_PY = os.path.expanduser(os.environ.get("OWL_DETECT_PY", "~/barn-owl-candidates/v3-3214f2a0/.venv/bin/python"))
DETECT_WORKER = os.path.join(os.path.dirname(os.path.abspath(__file__)), "rat_worker.py")
DETECT_MODEL_NAME = os.environ.get("OWL_DETECT_NAME", "rat-litroom-v5")
BOX_HOLD = 0.6  # seconds a box stays drawn after the frame it was found in
# The model confirms a rat every couple of seconds while it stays in view; one saved sighting (a
# Tiger Data row and a Solana anchor, which costs a fee) per this many seconds is plenty.
SIGHTING_GAP = float(os.environ.get("OWL_DETECT_GAP", 30))
# --mode picks the full-sensor 2x2-binned mode. Without it, asking for 640x480
# selects the sensor's 640x480 mode, which reads only the central 1280x960 of
# the 3280x2464 sensor -- the "zoomed in" look. OWL_CAM_EXTRA adds options such
# as "--gain 8 --shutter 30000 --awb greyworld".
# Zoom is a centred crop (--roi) of that binned image. Up to 2.5x the crop is
# still at least 640x480 sensor pixels, so it is real detail, not an upscale.
def cam_args(zoom):
    args = ["rpicam-vid", "-n", "-t", "0", "--codec", "mjpeg", "--quality", "80",
            "--mode", "1640:1232:10:P", "--width", "640", "--height", "480",
            "--framerate", str(FPS)]
    if zoom > 1:
        side = 1 / zoom
        off = (1 - side) / 2
        args += ["--roi", f"{off:.4f},{off:.4f},{side:.4f},{side:.4f}"]
    return args + shlex.split(os.environ.get("OWL_CAM_EXTRA", "")) + ["-o", "-"]


def preview(jpeg):
    """Shrink a frame for the dashboard (and the copies MongoDB keeps)."""
    if Image is None:
        return jpeg
    try:
        im = Image.open(io.BytesIO(jpeg)).convert("RGB").resize(PREVIEW_SIZE, Image.BILINEAR)
        out = io.BytesIO()
        im.save(out, "JPEG", quality=PREVIEW_QUALITY)
        return out.getvalue()
    except Exception:
        return jpeg


def log(*a):
    print(time.strftime("%H:%M:%S"), *a, flush=True)


class Camera:
    """Runs rpicam-vid only while someone is watching and keeps the newest JPEG."""

    def __init__(self, on_frame=()):
        self.proc = None
        self.frame = None
        self.frame_id = 0
        self.on_frame = on_frame
        self.zoom = 1.0

    @property
    def running(self):
        return self.proc is not None and self.proc.poll() is None

    def start(self, zoom=None):
        if zoom is not None and zoom != self.zoom:
            self.zoom = zoom
            if self.running:  # the crop is fixed at launch, so relaunch
                log(f"zoom {zoom}x")
                self.stop()
        if self.running:
            return
        log(f"camera on ({self.zoom}x)")
        self.proc = subprocess.Popen(cam_args(self.zoom), stdout=subprocess.PIPE, stderr=subprocess.DEVNULL)
        threading.Thread(target=self._read, args=(self.proc,), daemon=True).start()

    def stop(self):
        if self.proc:
            log("camera off")
            self.proc.terminate()
            try:
                self.proc.wait(3)
            except subprocess.TimeoutExpired:
                self.proc.kill()
        self.proc = None

    def _read(self, proc):
        # Each MJPEG frame is a complete JPEG: FFD8 ... FFD9.
        buf = b""
        while True:
            chunk = proc.stdout.read1(65536)
            if not chunk:
                return
            buf += chunk
            while True:
                start = buf.find(b"\xff\xd8")
                end = buf.find(b"\xff\xd9", start + 2) if start >= 0 else -1
                if end < 0:
                    buf = buf[start:] if start >= 0 else b""
                    break
                self.frame = buf[start:end + 2]
                self.frame_id += 1
                for fn in self.on_frame:
                    fn(self.frame)
                buf = buf[end + 2:]


class Recorder:
    """Writes every camera frame to <REC_DIR>/<time>_<id>.mjpeg while the
    dashboard says a recording is on, plus a .txt with each frame's time in ms
    since the start (the camera can drop frames, so don't assume exactly FPS)."""

    def __init__(self):
        self.lock = threading.Lock()
        self.f = self.times = None
        self.info = None  # reported to the dashboard; kept until "done" is delivered

    @property
    def active(self):
        return self.f is not None

    def start(self, rec_id):
        with self.lock:
            if self.info and self.info["id"] == rec_id:
                return
            self._close()
            os.makedirs(REC_DIR, exist_ok=True)
            path = os.path.join(REC_DIR, time.strftime("%Y%m%d-%H%M%S") + f"_{rec_id}.mjpeg")
            self.f = open(path, "wb")
            self.times = open(path[:-len(".mjpeg")] + ".txt", "w")
            self.t0 = time.monotonic()
            self.info = {"id": rec_id, "file": path, "frames": 0, "bytes": 0, "fps": FPS, "done": False}
            log("recording to", path)

    def write(self, jpeg):
        with self.lock:
            if not self.f:
                return
            self.f.write(jpeg)
            self.times.write(f"{(time.monotonic() - self.t0) * 1000:.1f}\n")
            self.info["frames"] += 1
            self.info["bytes"] += len(jpeg)

    def stop(self):
        with self.lock:
            self._close()

    def expired(self):
        return self.active and time.monotonic() - self.t0 > REC_MAX

    def _close(self):
        if self.f:
            self.f.close()
            self.times.close()
            self.f = self.times = None
            self.info["done"] = True
            log(f"recording saved: {self.info['file']} ({self.info['frames']} frames)")
            uploader.kick()

    def writing(self, path):
        with self.lock:
            return bool(self.f) and self.info["file"] == path

    def report(self):
        with self.lock:
            return dict(self.info) if self.info else None

    def delivered(self, report):
        with self.lock:
            if report and report["done"] and self.info and self.info["id"] == report["id"] and self.info["done"]:
                self.info = None


class Streamer:
    """Pushes every frame to STREAM_URL/api/stream-in over one chunked POST
    while someone has the 15 fps view open. The droplet fans the frames out
    to viewers and hangs up once nobody is watching."""

    def __init__(self):
        self.want = False
        self.thread = None
        self.cond = threading.Condition()
        self.latest = None
        self.latest_id = 0

    def push(self, jpeg):
        if self.want:
            with self.cond:
                self.latest, self.latest_id = jpeg, self.latest_id + 1
                self.cond.notify_all()

    def set(self, on):
        self.want = on and bool(STREAM_URL)
        if self.want and not (self.thread and self.thread.is_alive()):
            self.thread = threading.Thread(target=self._run, daemon=True)
            self.thread.start()
        if not self.want:
            with self.cond:
                self.cond.notify_all()

    def _run(self):
        u = urllib.parse.urlsplit(STREAM_URL)
        conn_cls = http.client.HTTPSConnection if u.scheme == "https" else http.client.HTTPConnection
        conn = conn_cls(u.netloc, timeout=15)
        sent = self.latest_id
        try:
            conn.putrequest("POST", "/api/stream-in")
            conn.putheader("Authorization", f"Bearer {TOKEN}")
            conn.putheader("Content-Type", "application/octet-stream")
            conn.putheader("Transfer-Encoding", "chunked")
            conn.endheaders()
            log("15 fps stream on")
            while self.want:
                with self.cond:
                    self.cond.wait_for(lambda: self.latest_id != sent or not self.want, timeout=5)
                    if not self.want or self.latest_id == sent:
                        continue
                    data, sent = self.latest, self.latest_id
                conn.send(b"%x\r\n" % len(data) + data + b"\r\n")
            conn.send(b"0\r\n\r\n")
            conn.getresponse().read()
        except Exception as e:  # the droplet hangs up when nobody is watching
            log("15 fps stream ended:", e)
        finally:
            conn.close()
            log("15 fps stream off")


class Uploader:
    """Sends each finished recording (.txt, then .mjpeg) to the droplet so the
    dashboard can play it at 15 fps. Retries until it works, so recordings made
    offline go up later; a .uploaded marker next to the file means done. The
    Pi keeps its own copy either way."""

    def __init__(self):
        self.wake = threading.Event()
        self.wake.set()  # catch up on anything left from before a restart
        threading.Thread(target=self._run, daemon=True).start()

    def kick(self):
        self.wake.set()

    def _run(self):
        while True:
            self.wake.wait(120)
            self.wake.clear()
            for mjpeg in sorted(glob.glob(os.path.join(REC_DIR, "*.mjpeg"))):
                base = mjpeg[:-len(".mjpeg")]
                if os.path.exists(base + ".uploaded") or recorder.writing(mjpeg):
                    continue
                rec_id = base.rsplit("_", 1)[-1]
                try:
                    status = self._put(rec_id, "txt", base + ".txt")
                    if status == 200:
                        status = self._put(rec_id, "mjpeg", mjpeg)
                    if status in (200, 404):  # 404: deleted on the dashboard
                        open(base + ".uploaded", "w").write(str(status))
                        log(f"upload {os.path.basename(mjpeg)}: {'done' if status == 200 else 'skipped (deleted)'}")
                    else:
                        raise RuntimeError(f"HTTP {status}")
                except Exception as e:
                    log(f"upload {os.path.basename(mjpeg)} failed, will retry: {e}")
                    break

    def _put(self, rec_id, kind, path):
        if not os.path.exists(path):
            return 200
        u = urllib.parse.urlsplit(STREAM_URL)
        conn_cls = http.client.HTTPSConnection if u.scheme == "https" else http.client.HTTPConnection
        conn = conn_cls(u.netloc, timeout=60)
        try:
            conn.putrequest("POST", f"/api/video-in?id={rec_id}&kind={kind}")
            conn.putheader("Authorization", f"Bearer {TOKEN}")
            conn.putheader("Content-Type", "application/octet-stream")
            conn.putheader("Content-Length", str(os.path.getsize(path)))
            conn.endheaders()
            with open(path, "rb") as f:
                while chunk := f.read(1 << 20):
                    conn.send(chunk)
            r = conn.getresponse()
            r.read()
            return r.status
        finally:
            conn.close()


class RatDetector:
    """Runs rat_worker.py while the dashboard has "Rat detection" on. The camera
    thread hands it a frame only when it is idle (the newest frame, never a
    queue), so detection can't slow the camera, the stream or a recording.
    Boxes from the latest result are drawn onto frames shown on the dashboard."""

    def __init__(self):
        self.proc = None
        self.busy = False
        self.want = False
        self.lock = threading.Lock()
        self.rats = []           # [[x, y, w, h, conf], ...] from the latest result
        self.boxes_at = 0.0
        self.ms = None           # inference time of the latest frame
        self.times = []          # result times over the last few seconds, for fps
        self.events = 0
        self.last_event = None
        self.error = None
        self.model = None
        self.fed = None          # the frame the worker is working on (its result goes with it)

    @property
    def running(self):
        return self.proc is not None and self.proc.poll() is None

    def set(self, on):
        self.want = on
        if on and not self.running:
            self.start()
        elif not on and self.proc:
            self.stop()

    def start(self):
        if not os.path.exists(DETECT_PY):
            self.error = f"detector venv not found ({DETECT_PY})"
            return
        log("rat detection on")
        self.error, self.model, self.busy = None, None, True  # busy until the model reports ready
        self.proc = subprocess.Popen([DETECT_PY, "-u", DETECT_WORKER], stdin=subprocess.PIPE,
                                     stdout=subprocess.PIPE, stderr=subprocess.PIPE)
        threading.Thread(target=self._read, args=(self.proc,), daemon=True).start()
        threading.Thread(target=self._errors, args=(self.proc,), daemon=True).start()

    def stop(self):
        log("rat detection off")
        proc, self.proc = self.proc, None
        try:
            proc.stdin.close()
            proc.terminate()
            proc.wait(3)
        except Exception:
            proc.kill()
        with self.lock:
            self.rats, self.ms, self.times = [], None, []

    def feed(self, jpeg):
        """Camera thread: hand over this frame if the worker is free."""
        if self.busy or not self.running:
            return
        self.busy = True
        self.fed = jpeg
        try:
            self.proc.stdin.write(len(jpeg).to_bytes(4, "big") + jpeg)
            self.proc.stdin.flush()
        except Exception:
            self.busy = False

    def _read(self, proc):
        for line in proc.stdout:
            try:
                r = json.loads(line)
            except ValueError:
                continue
            now = time.monotonic()
            if r.get("ready"):
                self.model = r.get("model")
                log(f"rat model {self.model} loaded")
            elif r.get("error"):
                self.error = r["error"]
            else:
                with self.lock:
                    self.rats, self.ms = r["rats"], r["ms"]
                    if self.rats:
                        self.boxes_at = now
                    self.times = [t for t in self.times if now - t < 3] + [now]
                if r.get("event"):
                    self.sighting(r["event"], self.fed)
            self.busy = False
        if self.proc is proc and self.want:  # died on its own: the next sync restarts it
            self.error = self.error or f"detector exited ({proc.poll()})"
            self.proc = None

    def _errors(self, proc):
        for line in proc.stderr:
            text = line.decode(errors="replace").strip()
            if text:
                log("detector:", text)
                self.error = text[-200:]

    def sighting(self, ev, frame):
        now = time.monotonic()
        if self.last_event is not None and now - self.last_event < SIGHTING_GAP:
            return
        self.events += 1
        self.last_event = now
        x, y, w, h = ev["box"]
        log(f"rat sighted ({ev['conf']:.2f}, {ev['hits']} frames)")
        rec = recorder.report()
        # The picture is the exact frame the model confirmed, with its boxes drawn on (full 640x480).
        body = {"label": "rat", "confidence": ev["conf"], "box": [x, y, w, h], "model": DETECT_MODEL_NAME,
                "ts": time.strftime("%Y-%m-%dT%H:%M:%S", time.gmtime()) + "Z",
                **({"image": base64.b64encode(self.annotate(frame)).decode()} if frame else {}),
                **({"recording": rec["id"], "frame": rec["frames"]} if rec and not rec["done"] else {})}
        threading.Thread(target=self._post, args=(body,), daemon=True).start()

    def _post(self, body):
        url = URLS[current][:-len("/api/pi")] + "/api/detections"
        req = urllib.request.Request(url, data=json.dumps(body).encode(), method="POST", headers={
            "Content-Type": "application/json", "Authorization": f"Bearer {TOKEN}"})
        try:
            urllib.request.urlopen(req, timeout=10).read()
        except Exception as e:
            log("could not save the sighting:", e)

    def annotate(self, jpeg):
        """The frame with the latest rat boxes drawn on, or the frame untouched."""
        with self.lock:
            rats = self.rats if self.running and time.monotonic() - self.boxes_at < BOX_HOLD else []
        if not rats or Image is None:
            return jpeg
        try:
            im = Image.open(io.BytesIO(jpeg)).convert("RGB")
            d = ImageDraw.Draw(im)
            W, H = im.size
            for x, y, w, h, conf in rats:
                box = (x * W, y * H, (x + w) * W, (y + h) * H)
                d.rectangle(box, outline=(255, 64, 64), width=3)
                label = f"rat {conf:.0%}"
                tw = d.textlength(label) + 8
                ty = box[1] - 14 if box[1] >= 14 else box[3]
                d.rectangle((box[0], ty, box[0] + tw, ty + 14), fill=(255, 64, 64))
                d.text((box[0] + 4, ty + 1), label, fill=(255, 255, 255))
            out = io.BytesIO()
            im.save(out, "JPEG", quality=80)
            return out.getvalue()
        except Exception:
            return jpeg

    def status(self):
        with self.lock:
            fps = (len(self.times) - 1) / (self.times[-1] - self.times[0]) if len(self.times) > 2 else None
            return {
                "on": self.running, "ready": self.model is not None, "model": self.model,
                "fps": round(fps, 1) if fps else None, "ms": self.ms, "rats": len(self.rats),
                "sightings": self.events,
                "lastSightingAgo": None if self.last_event is None else time.monotonic() - self.last_event,
                "error": self.error,
            }


pir = MotionSensor(PIR_PIN)
ir = DigitalOutputDevice(IR_PIN, initial_value=False)
recorder = Recorder()
uploader = Uploader()
streamer = Streamer()
detector = RatDetector()
# The team's live-worker handoff (poc vision/pi/LIVE_BRIDGE.md). Disabled unless OWL_DETECT_SOCKET is set.
# The bridge uses stdlib only and does not wait for detector inference in the camera callback.
handoff = None
try:
    from live_bridge import from_env
    handoff = from_env()
except Exception as e:
    log("detector handoff disabled:", type(e).__name__, e)
# The recorder gets the raw frame; only what is shown on the dashboard gets boxes.
callbacks = (recorder.write, lambda f: streamer.push(detector.annotate(f)) if streamer.want else None, detector.feed)
if handoff is not None:
    callbacks += (handoff,)
cam = Camera(on_frame=callbacks)
wake = threading.Event()
last_motion = None
motion_seen = False  # latched between syncs so short motion isn't missed
ir_timer = None
ir_until = None


def on_motion():
    global last_motion, motion_seen
    last_motion = time.monotonic()
    motion_seen = True
    wake.set()


pir.when_motion = on_motion
pir.when_no_motion = wake.set


def set_ir(on):
    global ir_timer, ir_until
    if ir_timer:
        ir_timer.cancel()
        ir_timer = ir_until = None
    if on:
        ir.on()
        ir_until = time.monotonic() + IR_MAX_ON
        ir_timer = threading.Timer(IR_MAX_ON, lambda: (log("IR auto-off"), set_ir(False), wake.set()))
        ir_timer.daemon = True
        ir_timer.start()
    else:
        ir.off()
    log("IR", "on" if on else "off")


current = 0          # index into URLS
on_backup_since = 0.0
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

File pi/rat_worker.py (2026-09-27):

#!/usr/bin/env python3
"""Rat detector for agent.py: runs the team's ONNX model (poc vision/pi/detect.py) on the frames the agent hands it.

agent.py starts this when "Rat detection" is switched on in the dashboard and stops it when switched off. It
runs in its own venv (numpy, OpenCV, ONNX Runtime; see poc vision/pi/README.md) so the agent's system Python
stays as it is.

stdin:  frames, each a 4-byte big-endian length and a JPEG. The agent sends one only when the previous
        result has come back, so this always works on the newest frame and never builds a backlog.
stdout: one JSON line per frame:
        {"rats": [[x, y, w, h, conf], ...], "persons": [...], "ms": 58.1,
         "event": {"conf": 0.87, "box": [x, y, w, h], "hits": 3} | null}
        Boxes are normalised, top-left + size. "event" is set when the model's three-hits-in-a-second gate
        fires (the same rule the team's live worker uses), so a sighting is one confirmed rat, not one frame.
        The first line is {"ready": true, "model": "<sha256 prefix>"} once the model has loaded.

Env: OWL_DETECT_DIR (holds detect.py and the model), OWL_DETECT_MODEL (default rat.onnx), OWL_DETECT_SHA256
(refuse to run a different model file), OWL_DETECT_CONF (default 0.70, the threshold the team locked).
"""
import hashlib
import json
import os
import struct
import sys
import time

DIR = os.path.expanduser(os.environ.get("OWL_DETECT_DIR", "~/barn-owl-candidates/v5-652a05e8"))
MODEL = os.path.join(DIR, os.environ.get("OWL_DETECT_MODEL", "rat.onnx"))
SHA256 = os.environ.get("OWL_DETECT_SHA256", "")
CONF = float(os.environ.get("OWL_DETECT_CONF", 0.70))

sys.path.insert(0, DIR)
import cv2  # noqa: E402
import numpy as np  # noqa: E402
import detect  # noqa: E402  (the team's detector: preprocessing, decoding, person rules, event gate)


def out(obj):
    sys.stdout.write(json.dumps(obj, separators=(",", ":")) + "\n")
    sys.stdout.flush()


def main():
    digest = hashlib.sha256(open(MODEL, "rb").read()).hexdigest()
    if SHA256 and digest != SHA256:
        out({"error": f"model hash {digest[:12]} is not the expected {SHA256[:12]}"})
        return 1
    det = detect.Detector(MODEL, conf=CONF, iou=detect.IOU)
    gate = detect.EventGate()
    out({"ready": True, "model": digest[:12]})
    inp = sys.stdin.buffer
    while True:
        head = inp.read(4)
        if len(head) < 4:
            return 0
        (n,) = struct.unpack(">I", head)
        jpeg = inp.read(n)
        if len(jpeg) < n:
            return 0
        img = cv2.imdecode(np.frombuffer(jpeg, np.uint8), cv2.IMREAD_COLOR)
        if img is None:
            out({"rats": [], "persons": [], "ms": 0, "event": None})
            continue
        t0 = time.perf_counter()
        rats, persons = detect.apply_rules(det.infer(img))
        ms = (time.perf_counter() - t0) * 1000
        best = max(rats, key=lambda d: d.conf) if rats else None
        fired = gate.update(time.monotonic(), best)
        out({
            "rats": [d.bbox + [round(d.conf, 3)] for d in rats],
            "persons": [d.bbox + [round(d.conf, 3)] for d in persons],
            "ms": round(ms, 1),
            "event": {"conf": round(fired[0].conf, 3), "box": fired[0].bbox, "hits": fired[1]} if fired else None,
        })


if __name__ == "__main__":
    sys.exit(main())

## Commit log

2026-09-25 first commit
    Pi 5 camera+PIR node: test scripts, IR capture samples, parametric enclosure STLs, handoff docs.
    [base_no_pisugar.stl, base_with_pisugar.stl, enclosure.scad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]
2026-09-27 Dashboard (barn-owl.tech + Vercel), Pi agent, v2 enclosure, deploy scripts and handoffs
    - dashboard/: Node dashboard served at /admin on the droplet and on Vercel (MongoDB, Tiger Data,
    Solana recording hashes, recordings/videos, read-only agent token for the Grok assistant)
    - dashboard/deploy/: droplet provisioning, Caddy site, team app deploy (fetches the city bake
    from the city-bake-v1 release), poc-api service
    - pi/: the node's agent and systemd unit
    - enclosure/v2/: current case
    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
    [v2_base_pisugar.stl, v2_base_usb.stl, v2_led_diffuser.stl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]
2026-09-27 Rat detection switch on the dashboard: the Pi runs the team's V5 model on live frames
    - pi/rat_worker.py runs vision/pi/detect.py (poc) in the detector venv on the newest frame only
    - agent.py starts/stops it from the dashboard, draws boxes on the preview and 15 fps view
    (recordings stay clean), and POSTs at most one sighting per 30 s to /api/detections
    - dashboard: api/detect.js toggle (auto-off after 30 min), status next to the IR switch
    Claude-Session: https://claude.ai/code/session_01MMvjR6JqtSR6hybZLAYrWt
2026-09-27 Keep the team's live-worker frame handoff in the agent alongside the rat switch
    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
2026-09-27 Each rat sighting carries its boxed frame, and Solana vouches for the picture too
    - Pi sends the exact frame the model confirmed (boxes drawn) with each sighting
    - dashboard stores it in MongoDB by SHA-256; the hash goes into the Tiger row
    (image_sha256) and the anchored payload (v2; v1 sightings hash exactly as before)
    - GET /api/detections lists each sighting with its Solana anchor; ?image=<sha> serves the picture
    - Solana tab Verify re-hashes the stored picture and shows it
    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
2026-09-27 Solana tab: View opens what each anchor is about
    A recording plays (with its AI sightings as jump points); a sighting shows the exact frame the model
    analysed, and seeks the recording to that frame when one was running.
    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
